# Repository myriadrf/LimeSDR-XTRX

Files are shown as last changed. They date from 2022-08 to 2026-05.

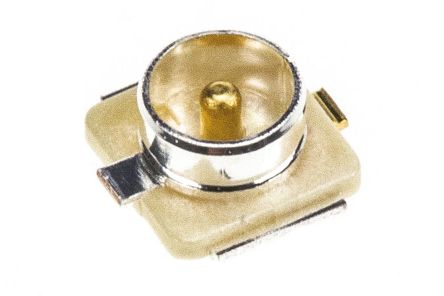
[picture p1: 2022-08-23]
hardware/rev5/Project Outputs/Pics/UFL connector.jpg

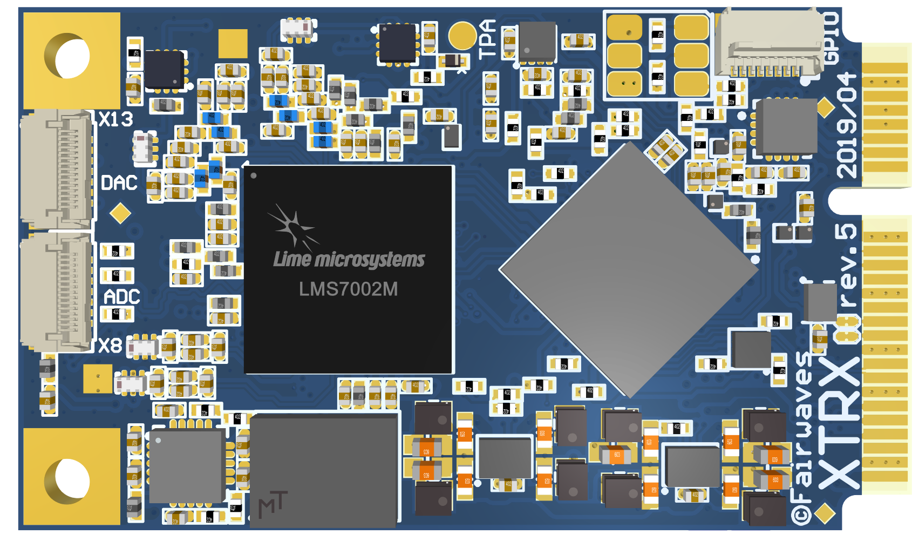
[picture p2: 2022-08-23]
hardware/rev5/Project Outputs/Pics/Bot.png

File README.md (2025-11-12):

# LimeSDR XTRX

LimeSDR XTRX is Small form factor mini PCIe expansion card Software Defined Radio (SDR) board. It provides a hardware platform for developing and prototyping high-performance and logic-intensive digital and RF designs based on Xilinx’s XC7A50T-2CPG236I FPGA and Lime Microsystems transceiver chipsets.

## Contents

The directory structure is as follows:

      hardware/<version>/
          OutputJobs/            - Output jobs
          PCB/                   - PCB design
          Project Outputs/       - BOM, rule check reports, Gerbers, pick & place files, PDFs
          Schematics/            - Schematic diagrams

The FPGA gateware is located in the [LimeSDR-XTRX_GW repo](https://github.com/myriadrf/LimeSDR-XTRX_GW).

## Documentation

The documentation sources for this project have been moved to the *docs* branch.

* [Hardware](https://limesdr-xtrx.myriadrf.org/)
* [Drivers](https://wiki.myriadrf.org/Lime_Suite) (Lime Suite)

## Licensing

The hardware designs are licensed under the Solderpad Hardware License v2.1.

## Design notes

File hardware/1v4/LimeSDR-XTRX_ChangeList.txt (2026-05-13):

Changes:
LimeSDR-XTRX_1v4(_DB)_DFMr0 created from LimeSDR-XTRX_1v3(_DB)_DFMr1:
 - Changed LMK buffer
 - Change USB FIFO chip because of EOL
 - Changed external CLK connectors from U.FL to MHF4
 - Added LMS TSTAO and TSTDO pin connections
 - Updated schematic template
 - All DFM files refreshed

LimeSDR-XTRX_1v3(_DB)_DFMr1:
 - BOM and schematic refreshed because of IC17 comment update
 - Other files (including DFM) left unchanged

LimeSDR-XTRX_1v3(_DB)_DFMr0:
 - Initial version

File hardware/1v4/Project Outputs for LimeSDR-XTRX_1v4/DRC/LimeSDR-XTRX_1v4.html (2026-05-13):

Altium

# Design Rule Verification Report

Date: | | 2026-05-13
Time: | | 12:01:15
Elapsed Time: | | 00:00:28
Filename: | | d:\LimePCBs\LimeSDR-XTRX\GIT\hardware\1v4\PCB\LimeSDR-XTRX_1v4.PcbDoc

Warnings: | | 0
Rule Violations: | | 0

## Summary

Warnings | Count
Total | 0

Rule Violations | Count
Clearance Constraint (Gap=0.1mm) (All),(All) | 0
Clearance Constraint (Gap=0.076mm) (WithinRoom('FPGA_fanout')),(All) | 0
Short-Circuit Constraint (Allowed=No) (All),(All) | 0
Un-Routed Net Constraint ( (All) ) | 0
Modified Polygon (Allow modified: No), (Allow shelved: No) | 0
Width Constraint (Min=0.1mm) (Max=7mm) (Preferred=0.2mm) (All) | 0
Width Constraint (Min=0.076mm) (Max=5mm) (Preferred=0.127mm) (WithinRoom('FPGA_fanout')) | 0
Width Constraint (Min=0.1mm) (Max=5mm) (Preferred=0.2mm) (All) | 0
Routing Layers(All) | 0
Routing Via (MinHoleWidth=0.15mm) (MaxHoleWidth=4.5mm) (PreferredHoleWidth=0.2mm) (MinWidth=0.3mm) (MaxWidth=5mm) (PreferedWidth=0.4mm) (All) | 0
Differential Pairs Uncoupled Length using the Gap Constraints (Min=0.1mm) (Max=0.3mm) (Prefered=0.1mm) and Width Constraints (Min=0.1mm) (Max=0.3mm) (Prefered=0.1mm) (InNetClass('RX_RF')) | 0
Differential Pairs Uncoupled Length using the Gap Constraints (Min=0.1mm) (Max=0.14mm) (Prefered=0.1mm) and Width Constraints (Min=0.1mm) (Max=0.2mm) (Prefered=0.1mm) (InNetClass('TX_RF')) | 0
Differential Pairs Uncoupled Length using the Gap Constraints (Min=0.1mm) (Max=0.3mm) (Prefered=0.14mm) and Width Constraints (Min=0.2mm) (Max=0.2mm) (Prefered=0.2mm) (InNetClass('FX3_DATA')) | 0
Differential Pairs Uncoupled Length using the Gap Constraints (Min=0.1mm) (Max=0.2mm) (Prefered=0.1mm) and Width Constraints (Min=0.1mm) (Max=0.4mm) (Prefered=0.1mm) (InNet('FX3_XTAL_N') or InNet('FX3_XTAL_P')) | 0
Differential Pairs Uncoupled Length using the Gap Constraints (Min=0.1mm) (Max=0.3mm) (Prefered=0.1mm) and Width Constraints (Min=0.1mm) (Max=0.5mm) (Prefered=0.2mm) (All) | 0
Power Plane Connect Rule(Relief Connect )(Expansion=0.508mm) (Conductor Width=0.254mm) (Air Gap=0.254mm) (Entries=4) (All) | 0
Hole Size Constraint (Min=0.15mm) (Max=10mm) (All) | 0
Pads and Vias to follow the Drill pairs settings | 0
Hole To Hole Clearance (Gap=0.15mm) (All),(All) | 0
Minimum Solder Mask Sliver (Gap=0.05mm) (All),(All) | 0
Net Antennae (Tolerance=0mm) (All) | 0
Matched Lengths(Tolerance=5mm) (InNetClass('FT_FIFO')) | 0
Matched Lengths(Tolerance=7.5mm) (InNetClass('LMS_PORT2')) | 0
Matched Lengths(Tolerance=7mm) (InNetClass('LMS_PORT1')) | 0
Component Clearance Constraint ( Horizontal Gap = -1mm, Vertical Gap = Infinite ) (HasFootprint('PCIe_MiniCard')),(All) | 0
Component Clearance Constraint ( Horizontal Gap = 0.01mm, Vertical Gap = 0.254mm ) (All),(All) | 0
Component Clearance Constraint ( Horizontal Gap = -1mm, Vertical Gap = Infinite ) (HasFootprint('MAX40200ANS+_IDEAL_DIODE_4WLP')),(HasFootprint('SOT23-5_v1')) | 0
Component Clearance Constraint ( Horizontal Gap = -10mm, Vertical Gap = Infinite ) (InComponent('MECH*') or InComponent('J3')),(All) | 0
Component Clearance Constraint ( Horizontal Gap = -1mm, Vertical Gap = Infinite ) (InComponent('R63') or InComponent('R66')),(InComponent('R63') or InComponent('R66')) | 0
Height Constraint (Min=0mm) (Max=25.4mm) (Prefered=12.7mm) (All) | 0
Total | 0

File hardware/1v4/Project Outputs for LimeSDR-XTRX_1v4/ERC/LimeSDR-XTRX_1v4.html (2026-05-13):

Altium

# Electrical Rule Check Report

Date: | | 2026-05-13
Time: | | 12:01:45
Filename: | | d:\LimePCBs\LimeSDR-XTRX\GIT\hardware\1v4\Project Outputs for LimeSDR-XTRX_1v4\ERC\LimeSDR-XTRX_1v4.html

Class | Document | Message
Warning | 10_Clock.SchDoc | FPGA_CLK contains IO Pin and Output Pin objects (Pin IC7-N17)

Warning

09_Misc.SchDoc

GND contains IO Pin and Power Pin objects (Pin IC30-2,Pin IC27-2,Pin IC25-2,Pin IC17-4,Pin IC13-4,Pin IC2-4,Pin IC4-7,Pin IC3-7,Pin IC7-A1,Pin IC7-A3,Pin IC7-A5,Pin IC7-A7,Pin IC7-A9,Pin IC7-A19,Pin IC7-B3,Pin IC7-B5,Pin IC7-B7,Pin IC7-B9,Pin IC7-B14,Pin IC7-C2,Pin IC19-C3,Pin IC7-C3,Pin IC7-C4,Pin IC7-C6,Pin IC7-C10,Pin IC7-C12,Pin IC7-C19,Pin IC7-D3,Pin IC7-E3,Pin IC7-E17,Pin IC7-E18,Pin IC4-EP,Pin IC3-EP,Pin IC7-F1,Pin IC7-F2,Pin IC7-F19,Pin IC7-G1,Pin IC7-G8,Pin IC7-G11,Pin IC7-H7,Pin IC7-H8,Pin IC7-H11,Pin IC7-H12,Pin IC7-H18,Pin IC7-J8,Pin IC7-J9,Pin IC7-J11,Pin IC7-J12,Pin IC7-K8,Pin IC7-L8,Pin IC7-L9,Pin IC7-L11,Pin IC7-L19,Pin IC7-M9,Pin IC7-M13,Pin IC7-N9,Pin IC7-N12,Pin IC7-N13,Pin IC7-P2,Pin IC7-P18,Pin IC13-PAD,Pin IC2-PAD,Pin IC7-T19,Pin IC7-U6,Pin IC7-U9,Pin IC7-V13,Pin IC7-V18,Pin IC7-W1,Pin IC7-W12)
Warning | 09_Misc.SchDoc | GNSS_1PPS contains IO Pin and Output Pin objects (Pin IC7-P3)
Warning | 09_Misc.SchDoc | GNSS_FIX contains IO Pin and Output Pin objects (Pin IC7-R18)
Warning | 08_FPGA.SchDoc | Net C0_N has no driving source (Pin C96-2,Pin IC7-A8)
Warning | 08_FPGA.SchDoc | Net C0_P has no driving source (Pin C95-2,Pin IC7-B8)
Warning | 09_Misc.SchDoc | Net FPGA_CFG_CCLK has no driving source (Pin IC7-C11,Pin IC18-6)
Warning | 08_FPGA.SchDoc | Net FPGA_PRG_B has no driving source (Pin C105-1,Pin IC7-V10,Pin R43-2,Pin TP3-1)
Warning | 09_Misc.SchDoc | Net GNSS_ANT has no driving source (Pin ESD5-1,Pin IC11-3,Pin L1-1,Pin X5-1)
Warning | 05_LMS7002M_Misc.SchDoc | Net LMS_I2C_SCL has no driving source (Pin IC1-C27,Pin IC2-6,Pin R4-1)
Warning | 08_FPGA.SchDoc | Net M0 has no driving source (Pin IC7-V12,Pin R42-2)
Warning | 08_FPGA.SchDoc | Net MGTRREF_216 has no driving source (Pin IC7-C7,Pin R40-2)
Warning | 08_FPGA.SchDoc | Net NetC106_1 has no driving source (Pin C106-1,Pin IC7-A12,Pin R46-1,Pin R47-1,Pin R48-1)
Warning | 10_Clock.SchDoc | Net NetC156_2 has no driving source (Pin C156-2,Pin IC8-13)
Warning | 10_Clock.SchDoc | Net NetC165_2 has no driving source (Pin C165-2,Pin IC8-28)
Warning | 10_Clock.SchDoc | Net NetC172_2 has no driving source (Pin C172-2,Pin IC8-14)
Warning | 11_Power.SchDoc | Net NetC175_2 has no driving source (Pin C175-2,Pin FR54-2,Pin IC21-1,Pin IC21-6,Pin R105-1)
Warning | 10_Clock.SchDoc | Net NetC192_2 has no driving source (Pin C192-2,Pin IC8-27)
Warning | 11_Power.SchDoc | Net NetC203_2 has no driving source (Pin C203-2,Pin FR45-2,Pin IC26-1,Pin IC26-6,Pin R108-1)
Warning | 11_Power.SchDoc | Net NetC209_2 has no driving source (Pin C209-2,Pin FR49-2,Pin IC29-1,Pin IC29-6,Pin R115-1)
Warning | 11_Power.SchDoc | Net NetC220_2 has no driving source (Pin C220-2,Pin FR50-2,Pin IC32-1,Pin IC32-6,Pin R118-1)
Warning | 09_Misc.SchDoc | Net NetFR36_2 has no driving source (Pin FR36-2,Pin IC11-9)
Warning | 10_Clock.SchDoc | Net NetIC8_31 has no driving source (Pin IC8-31,Pin R149-2)
Warning | 10_Clock.SchDoc | Net NetIC17_2 has no driving source (Pin IC17-2,Pin R68-2,Pin R69-2)
Warning | 09_Misc.SchDoc | Net NetIC19_B1 has no driving source (Pin IC19-B1,Pin R81-2)
Warning | 11_Power.SchDoc | Net NetIC21_5 has no driving source (Pin IC21-5,Pin R106-2,Pin R107-1)
Warning | 11_Power.SchDoc | Net NetIC26_5 has no driving source (Pin IC26-5,Pin R112-2,Pin R113-1)
Warning | 11_Power.SchDoc | Net NetIC29_5 has no driving source (Pin IC29-5,Pin R116-2,Pin R117-1)
Warning | 11_Power.SchDoc | Net NetIC32_5 has no driving source (Pin IC32-5,Pin R122-2,Pin R123-1)
Warning | 08_FPGA.SchDoc | Net PCI_REF_CLK1_N has no driving source (Pin IC7-A10,Pin TP2-1)
Warning | 08_FPGA.SchDoc | Net PCI_REF_CLK1_P has no driving source (Pin IC7-B10,Pin TP1-1)
Warning | 08_FPGA.SchDoc | Net R0_N has no driving source (Pin C103-2,Pin IC7-A6)
Warning | 08_FPGA.SchDoc | Net R0_P has no driving source (Pin C101-2,Pin IC7-B6)
Warning | 08_FPGA.SchDoc | Net R1_N has no driving source (Pin C99-2,Pin IC7-A4)
Warning | 08_FPGA.SchDoc | Net R1_P has no driving source (Pin C97-2,Pin IC7-B4)
Warning | 08_FPGA.SchDoc | Net TCK_0 has no driving source (Pin IC7-C8,Pin R34-2,Pin R39-2)
Warning | 08_FPGA.SchDoc | Net TDI_0 has no driving source (Pin IC7-W10,Pin R35-2,Pin R37-2)
Warning | 08_FPGA.SchDoc | Net TMS_0 has no driving source (Pin IC7-W9,Pin R36-2,Pin R41-2)
Warning | 10_Clock.SchDoc | Net XO_VC has no driving source (Pin C184-1,Pin R66-2,Pin R67-2,Pin R70-1,Pin XO1-1)
Warning | 09_Misc.SchDoc | USB_DIR contains IO Pin and Output Pin objects (Pin IC7-B18)
Warning | 09_Misc.SchDoc | USB_NXT contains IO Pin and Output Pin objects (Pin IC7-A18)

Back to top

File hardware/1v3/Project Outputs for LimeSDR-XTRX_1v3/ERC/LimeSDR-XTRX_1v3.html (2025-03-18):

Altium

# Electrical Rule Check Report

Date: | | 2024-12-06
Time: | | 14:26:39
Filename: | | d:\LimePCBs\LimeSDR-XTRX\GIT\hardware\1v3\Project Outputs for LimeSDR-XTRX_1v3\ERC\LimeSDR-XTRX_1v3.html

Class | Document | Message

Warning

09_Misc.SchDoc

GND contains IO Pin and Power Pin objects (Pin IC30-2,Pin IC27-2,Pin IC25-2,Pin IC17-4,Pin IC13-4,Pin IC2-4,Pin IC4-7,Pin IC3-7,Pin IC7-A1,Pin IC7-A3,Pin IC7-A5,Pin IC7-A7,Pin IC7-A9,Pin IC7-A19,Pin IC7-B3,Pin IC7-B5,Pin IC7-B7,Pin IC7-B9,Pin IC7-B14,Pin IC7-C2,Pin IC7-C3,Pin IC7-C4,Pin IC7-C6,Pin IC7-C10,Pin IC7-C12,Pin IC7-C19,Pin IC7-D3,Pin IC7-E3,Pin IC7-E17,Pin IC7-E18,Pin IC4-EP,Pin IC3-EP,Pin IC7-F1,Pin IC7-F2,Pin IC7-F19,Pin IC7-G1,Pin IC7-G8,Pin IC7-G11,Pin IC7-H7,Pin IC7-H8,Pin IC7-H11,Pin IC7-H12,Pin IC7-H18,Pin IC7-J8,Pin IC7-J9,Pin IC7-J11,Pin IC7-J12,Pin IC7-K8,Pin IC7-K18,Pin IC7-L8,Pin IC7-L9,Pin IC7-L11,Pin IC7-L19,Pin IC7-M9,Pin IC7-M13,Pin IC7-N9,Pin IC7-N12,Pin IC7-N13,Pin IC7-P2,Pin IC13-PAD,Pin IC2-PAD,Pin IC7-T19,Pin IC7-U6,Pin IC7-U9,Pin IC7-V18,Pin IC7-W1,Pin IC7-W12)
Warning | 09_Misc.SchDoc | GNSS_1PPS contains IO Pin and Output Pin objects (Pin IC7-P3)
Warning | 09_Misc.SchDoc | GNSS_FIX contains IO Pin and Output Pin objects (Pin IC7-R18)
Warning | 01_Block_Diagram.SchDoc | Incorrect link between project variant "Default" and schematic component Component C185 100nF, 6.3V
Warning | 08_FPGA.SchDoc | Net C0_N has no driving source (Pin C96-2,Pin IC7-A8)
Warning | 08_FPGA.SchDoc | Net C0_P has no driving source (Pin C95-2,Pin IC7-B8)
Warning | 09_Misc.SchDoc | Net FPGA_CFG_CCLK has no driving source (Pin IC7-C11,Pin IC18-6)
Warning | 08_FPGA.SchDoc | Net FPGA_PRG_B has no driving source (Pin C105-1,Pin IC7-V10,Pin R43-2,Pin TP3-1)
Warning | 09_Misc.SchDoc | Net GNSS_ANT has no driving source (Pin ESD5-1,Pin IC11-3,Pin L1-1,Pin X5-1)
Warning | 05_LMS7002M_Misc.SchDoc | Net LMS_I2C_SCL has no driving source (Pin IC1-C27,Pin IC2-6,Pin R4-1)
Warning | 08_FPGA.SchDoc | Net M0 has no driving source (Pin IC7-V12,Pin R42-2)
Warning | 08_FPGA.SchDoc | Net MGTRREF_216 has no driving source (Pin IC7-C7,Pin R40-2)
Warning | 08_FPGA.SchDoc | Net NetC106_1 has no driving source (Pin C106-1,Pin IC7-A12,Pin R46-1,Pin R47-1,Pin R48-1)
Warning | 11_Power.SchDoc | Net NetC175_2 has no driving source (Pin C175-2,Pin FR54-2,Pin IC21-1,Pin IC21-6,Pin R105-1)
Warning | 11_Power.SchDoc | Net NetC203_2 has no driving source (Pin C203-2,Pin FR45-2,Pin IC26-1,Pin IC26-6,Pin R108-1)
Warning | 11_Power.SchDoc | Net NetC209_2 has no driving source (Pin C209-2,Pin FR49-2,Pin IC29-1,Pin IC29-6,Pin R115-1)
Warning | 11_Power.SchDoc | Net NetC220_2 has no driving source (Pin C220-2,Pin FR50-2,Pin IC32-1,Pin IC32-6,Pin R118-1)
Warning | 09_Misc.SchDoc | Net NetFR36_2 has no driving source (Pin FR36-2,Pin IC11-9)
Warning | 10_Clock.SchDoc | Net NetIC17_2 has no driving source (Pin IC17-2,Pin R68-2,Pin R69-2)
Warning | 11_Power.SchDoc | Net NetIC21_5 has no driving source (Pin IC21-5,Pin R106-2,Pin R107-1)
Warning | 11_Power.SchDoc | Net NetIC26_5 has no driving source (Pin IC26-5,Pin R112-2,Pin R113-1)
Warning | 11_Power.SchDoc | Net NetIC29_5 has no driving source (Pin IC29-5,Pin R116-2,Pin R117-1)
Warning | 11_Power.SchDoc | Net NetIC32_5 has no driving source (Pin IC32-5,Pin R122-2,Pin R123-1)
Warning | 08_FPGA.SchDoc | Net PCI_REF_CLK1_N has no driving source (Pin IC7-A10,Pin TP2-1)
Warning | 08_FPGA.SchDoc | Net PCI_REF_CLK1_P has no driving source (Pin IC7-B10,Pin TP1-1)
Warning | 08_FPGA.SchDoc | Net R0_N has no driving source (Pin C103-2,Pin IC7-A6)
Warning | 08_FPGA.SchDoc | Net R0_P has no driving source (Pin C101-2,Pin IC7-B6)
Warning | 08_FPGA.SchDoc | Net R1_N has no driving source (Pin C99-2,Pin IC7-A4)
Warning | 08_FPGA.SchDoc | Net R1_P has no driving source (Pin C97-2,Pin IC7-B4)
Warning | 08_FPGA.SchDoc | Net TCK_0 has no driving source (Pin IC7-C8,Pin R34-2,Pin R39-2)
Warning | 08_FPGA.SchDoc | Net TDI_0 has no driving source (Pin IC7-W10,Pin R35-2,Pin R37-2)
Warning | 08_FPGA.SchDoc | Net TMS_0 has no driving source (Pin IC7-W9,Pin R36-2,Pin R41-2)
Warning | 10_Clock.SchDoc | Net XO_VC has no driving source (Pin C184-1,Pin R66-2,Pin R67-2,Pin R70-1,Pin XO1-1)

Back to top

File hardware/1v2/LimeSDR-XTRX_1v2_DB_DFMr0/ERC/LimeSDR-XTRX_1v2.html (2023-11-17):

Altium

# Electrical Rule Check Report

Date: | | 2023-11-17
Time: | | 17:05:38
Filename: | | d:\LimePCBs\LimeSDR-XTRX\GIT\hardware\1v2\Project Outputs for LimeSDR-XTRX_1v2\ERC\LimeSDR-XTRX_1v2.html

Class | Document | Message

Warning

09_Misc.SchDoc

GND contains IO Pin and Power Pin objects (Pin IC30-2,Pin IC27-2,Pin IC25-2,Pin IC17-4,Pin IC13-4,Pin IC2-4,Pin IC4-7,Pin IC3-7,Pin IC7-A1,Pin IC7-A3,Pin IC7-A5,Pin IC7-A7,Pin IC7-A9,Pin IC7-A19,Pin IC7-B3,Pin IC7-B5,Pin IC7-B7,Pin IC7-B9,Pin IC7-B14,Pin IC7-C2,Pin IC7-C3,Pin IC7-C4,Pin IC7-C6,Pin IC7-C10,Pin IC7-C12,Pin IC7-C19,Pin IC7-D3,Pin IC7-E3,Pin IC7-E17,Pin IC7-E18,Pin IC4-EP,Pin IC3-EP,Pin IC7-F1,Pin IC7-F2,Pin IC7-F19,Pin IC7-G1,Pin IC7-G8,Pin IC7-G11,Pin IC7-H7,Pin IC7-H8,Pin IC7-H11,Pin IC7-H12,Pin IC7-H18,Pin IC7-J8,Pin IC7-J9,Pin IC7-J11,Pin IC7-J12,Pin IC7-K8,Pin IC7-K18,Pin IC7-L8,Pin IC7-L9,Pin IC7-L11,Pin IC7-L19,Pin IC7-M9,Pin IC7-M13,Pin IC7-N9,Pin IC7-N12,Pin IC7-N13,Pin IC7-P2,Pin IC13-PAD,Pin IC2-PAD,Pin IC7-T19,Pin IC7-U6,Pin IC7-U9,Pin IC7-V13,Pin IC7-V18,Pin IC7-W1,Pin IC7-W12)
Warning | 09_Misc.SchDoc | GNSS_1PPS contains IO Pin and Output Pin objects (Pin IC7-P3)
Warning | 09_Misc.SchDoc | GNSS_FIX contains IO Pin and Output Pin objects (Pin IC7-R18)
Warning | 08_FPGA.SchDoc | Net C0_N has no driving source (Pin C96-2,Pin IC7-A8)
Warning | 08_FPGA.SchDoc | Net C0_P has no driving source (Pin C95-2,Pin IC7-B8)
Warning | 09_Misc.SchDoc | Net FPGA_CFG_CCLK has no driving source (Pin IC7-C11,Pin IC18-6)
Warning | 08_FPGA.SchDoc | Net FPGA_PRG_B has no driving source (Pin C105-1,Pin IC7-V10,Pin R43-2,Pin TP3-1)
Warning | 09_Misc.SchDoc | Net GNSS_ANT has no driving source (Pin ESD5-1,Pin IC11-3,Pin L1-1,Pin X5-1)
Warning | 05_LMS7002M_Misc.SchDoc | Net LMS_I2C_SCL has no driving source (Pin IC1-C27,Pin IC2-6,Pin R4-1)
Warning | 08_FPGA.SchDoc | Net M0 has no driving source (Pin IC7-V12,Pin R42-2)
Warning | 08_FPGA.SchDoc | Net MGTRREF_216 has no driving source (Pin IC7-C7,Pin R40-2)
Warning | 08_FPGA.SchDoc | Net NetC106_1 has no driving source (Pin C106-1,Pin IC7-A12,Pin R46-1,Pin R47-1,Pin R48-1)
Warning | 10_Power.SchDoc | Net NetC192_2 has no driving source (Pin C192-2,Pin FR42-2,Pin IC21-1,Pin IC21-6,Pin R105-1)
Warning | 10_Power.SchDoc | Net NetC203_2 has no driving source (Pin C203-2,Pin FR45-2,Pin IC26-1,Pin IC26-6,Pin R108-1)
Warning | 10_Power.SchDoc | Net NetC209_2 has no driving source (Pin C209-2,Pin FR49-2,Pin IC29-1,Pin IC29-6,Pin R115-1)
Warning | 10_Power.SchDoc | Net NetC220_2 has no driving source (Pin C220-2,Pin FR50-2,Pin IC32-1,Pin IC32-6,Pin R118-1)
Warning | 09_Misc.SchDoc | Net NetFR36_2 has no driving source (Pin FR36-2,Pin IC11-9)
Warning | 09_Misc.SchDoc | Net NetIC17_2 has no driving source (Pin IC17-2,Pin R68-2,Pin R69-2)
Warning | 10_Power.SchDoc | Net NetIC21_5 has no driving source (Pin IC21-5,Pin R106-2,Pin R107-1)
Warning | 10_Power.SchDoc | Net NetIC26_5 has no driving source (Pin IC26-5,Pin R112-2,Pin R113-1)
Warning | 10_Power.SchDoc | Net NetIC29_5 has no driving source (Pin IC29-5,Pin R116-2,Pin R117-1)
Warning | 10_Power.SchDoc | Net NetIC32_5 has no driving source (Pin IC32-5,Pin R122-2,Pin R123-1)
Warning | 08_FPGA.SchDoc | Net PCI_REF_CLK1_N has no driving source (Pin IC7-A10,Pin TP2-1)
Warning | 08_FPGA.SchDoc | Net PCI_REF_CLK1_P has no driving source (Pin IC7-B10,Pin TP1-1)
Warning | 08_FPGA.SchDoc | Net R0_N has no driving source (Pin C103-2,Pin IC7-A6)
Warning | 08_FPGA.SchDoc | Net R0_P has no driving source (Pin C101-2,Pin IC7-B6)
Warning | 08_FPGA.SchDoc | Net R1_N has no driving source (Pin C99-2,Pin IC7-A4)
Warning | 08_FPGA.SchDoc | Net R1_P has no driving source (Pin C97-2,Pin IC7-B4)
Warning | 08_FPGA.SchDoc | Net TCK_0 has no driving source (Pin IC7-C8,Pin R34-2,Pin R39-2)
Warning | 08_FPGA.SchDoc | Net TDI_0 has no driving source (Pin IC7-W10,Pin R35-2,Pin R37-2)
Warning | 08_FPGA.SchDoc | Net TMS_0 has no driving source (Pin IC7-W9,Pin R36-2,Pin R41-2)
Warning | 09_Misc.SchDoc | Net XO_VC has no driving source (Pin C184-1,Pin R66-2,Pin R67-2,Pin R70-1,Pin XO1-1)

Back to top

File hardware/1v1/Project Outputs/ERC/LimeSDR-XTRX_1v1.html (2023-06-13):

Altium

# Electrical Rule Check Report

Date: | | 2023-04-14
Time: | | 16:12:55
Filename: | | E:\Saniok\Lime Micro\Lime PCBs\LimeSDR-XTRX\LimeSDR-XTRX_1v1\Altium Designer design files\Project Outputs for LimeSDR-XTRX_1v1\ERC\LimeSDR-XTRX_1v1.html

Class | Document | Message
Warning | 09_Misc.SchDoc | FPGA_CLK contains IO Pin and Output Pin objects (Pin IC7-N17)

Warning

09_Misc.SchDoc

GND contains IO Pin and Power Pin objects (Pin IC29-2,Pin IC26-2,Pin IC24-2,Pin IC16-4,Pin IC13-4,Pin IC2-4,Pin IC4-7,Pin IC3-7,Pin IC7-A1,Pin IC7-A3,Pin IC7-A5,Pin IC7-A7,Pin IC7-A9,Pin IC7-A19,Pin IC7-B3,Pin IC7-B5,Pin IC7-B7,Pin IC7-B9,Pin IC7-B14,Pin IC7-C2,Pin IC7-C3,Pin IC7-C4,Pin IC7-C6,Pin IC7-C10,Pin IC7-C12,Pin IC7-C19,Pin IC7-D3,Pin IC7-E3,Pin IC7-E17,Pin IC7-E18,Pin IC4-EP,Pin IC3-EP,Pin IC7-F1,Pin IC7-F2,Pin IC7-F19,Pin IC7-G1,Pin IC7-G8,Pin IC7-G11,Pin IC7-H7,Pin IC7-H8,Pin IC7-H11,Pin IC7-H12,Pin IC7-H18,Pin IC7-J8,Pin IC7-J9,Pin IC7-J11,Pin IC7-J12,Pin IC7-K8,Pin IC7-K18,Pin IC7-L8,Pin IC7-L9,Pin IC7-L11,Pin IC7-L19,Pin IC7-M9,Pin IC7-M13,Pin IC7-N9,Pin IC7-N12,Pin IC7-N13,Pin IC7-P2,Pin IC7-P18,Pin IC13-PAD,Pin IC2-PAD,Pin IC7-T19,Pin IC7-U6,Pin IC7-U9,Pin IC7-V18,Pin IC7-W1,Pin IC7-W12)
Warning | 09_Misc.SchDoc | GNSS_1PPS contains IO Pin and Output Pin objects (Pin IC7-P3)
Warning | 09_Misc.SchDoc | GNSS_FIX contains IO Pin and Output Pin objects (Pin IC7-R18)
Warning | 08_FPGA.SchDoc | Net C0_N has no driving source (Pin C96-2,Pin IC7-A8)
Warning | 08_FPGA.SchDoc | Net C0_P has no driving source (Pin C95-2,Pin IC7-B8)
Warning | 09_Misc.SchDoc | Net FPGA_CFG_CCLK has no driving source (Pin IC7-C11,Pin IC17-6)
Warning | 08_FPGA.SchDoc | Net FPGA_PRG_B has no driving source (Pin C105-1,Pin IC7-V10,Pin R43-2,Pin TP3-1)
Warning | 09_Misc.SchDoc | Net GNSS_ANT has no driving source (Pin ESD5-1,Pin IC10-3,Pin L1-1,Pin X5-1)
Warning | 05_LMS7002M_Misc.SchDoc | Net LMS_I2C_SCL has no driving source (Pin IC1-C27,Pin IC2-6,Pin R4-1)
Warning | 08_FPGA.SchDoc | Net M0 has no driving source (Pin IC7-V12,Pin R42-2)
Warning | 08_FPGA.SchDoc | Net MGTRREF_216 has no driving source (Pin IC7-C7,Pin R40-2)
Warning | 08_FPGA.SchDoc | Net NetC106_1 has no driving source (Pin C106-1,Pin IC7-A12,Pin R47-1,Pin R49-1,Pin R50-1)
Warning | 09_Misc.SchDoc | Net NetC157_2 has no driving source (Pin C157-2,Pin IC9-2,Pin R56-1)
Warning | 10_Power.SchDoc | Net NetC188_2 has no driving source (Pin C188-2,Pin FR43-2,Pin IC20-1,Pin IC20-6,Pin R103-1)
Warning | 10_Power.SchDoc | Net NetC199_2 has no driving source (Pin C199-2,Pin FR46-2,Pin IC25-1,Pin IC25-6,Pin R106-1)
Warning | 10_Power.SchDoc | Net NetC205_2 has no driving source (Pin C205-2,Pin FR49-2,Pin IC28-1,Pin IC28-6,Pin R113-1)
Warning | 10_Power.SchDoc | Net NetC216_2 has no driving source (Pin C216-2,Pin FR50-2,Pin IC31-1,Pin IC31-6,Pin R116-1)
Warning | 09_Misc.SchDoc | Net NetFR36_2 has no driving source (Pin FR36-2,Pin IC10-9)
Warning | 09_Misc.SchDoc | Net NetIC11_2 has no driving source (Pin IC11-2,Pin IC12-4,Pin IC14-2,Pin R58-1)
Warning | 09_Misc.SchDoc | Net NetIC16_2 has no driving source (Pin IC16-2,Pin R66-2,Pin R67-2)
Warning | 10_Power.SchDoc | Net NetIC20_5 has no driving source (Pin IC20-5,Pin R104-2,Pin R105-1)
Warning | 10_Power.SchDoc | Net NetIC25_5 has no driving source (Pin IC25-5,Pin R110-2,Pin R111-1)
Warning | 10_Power.SchDoc | Net NetIC28_5 has no driving source (Pin IC28-5,Pin R114-2,Pin R115-1)
Warning | 10_Power.SchDoc | Net NetIC31_5 has no driving source (Pin IC31-5,Pin R120-2,Pin R121-1)
Warning | 08_FPGA.SchDoc | Net PCI_REF_CLK1_N has no driving source (Pin IC7-A10,Pin TP2-1)
Warning | 08_FPGA.SchDoc | Net PCI_REF_CLK1_P has no driving source (Pin IC7-B10,Pin TP1-1)
Warning | 08_FPGA.SchDoc | Net R0_N has no driving source (Pin C103-2,Pin IC7-A6)
Warning | 08_FPGA.SchDoc | Net R0_P has no driving source (Pin C101-2,Pin IC7-B6)
Warning | 08_FPGA.SchDoc | Net R1_N has no driving source (Pin C99-2,Pin IC7-A4)
Warning | 08_FPGA.SchDoc | Net R1_P has no driving source (Pin C97-2,Pin IC7-B4)
Warning | 08_FPGA.SchDoc | Net TCK_0 has no driving source (Pin IC7-C8,Pin R34-2,Pin R39-2)
Warning | 08_FPGA.SchDoc | Net TDI_0 has no driving source (Pin IC7-W10,Pin R35-2,Pin R37-2)
Warning | 08_FPGA.SchDoc | Net TMS_0 has no driving source (Pin IC7-W9,Pin R36-2,Pin R41-2)
Warning | 09_Misc.SchDoc | Net XO_VC has no driving source (Pin C178-1,Pin R64-2,Pin R65-2,Pin R68-1,Pin XO1-1)

Back to top

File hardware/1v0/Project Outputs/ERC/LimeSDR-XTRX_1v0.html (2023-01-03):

Altium

# Electrical Rule Check Report

Date: | | 2022-12-29
Time: | | 14:01:02
Filename: | | E:\Saniok\Lime Micro\Lime PCBs\LimeSDR-XTRX_1v0\Altium Designer design files1\Project Outputs for LimeSDR-XTRX_1v0\ERC\LimeSDR-XTRX_1v0.html

Class | Document | Message
Warning | 09_Misc.SchDoc | FPGA_CLK contains IO Pin and Output Pin objects (Pin IC7-N17)

Warning

09_Misc.SchDoc

GND contains IO Pin and Power Pin objects (Pin IC29-2,Pin IC26-2,Pin IC24-2,Pin IC16-4,Pin IC13-4,Pin IC2-4,Pin IC4-7,Pin IC3-7,Pin IC7-A1,Pin IC7-A3,Pin IC7-A5,Pin IC7-A7,Pin IC7-A9,Pin IC7-A19,Pin IC7-B3,Pin IC7-B5,Pin IC7-B7,Pin IC7-B9,Pin IC7-B14,Pin IC7-C2,Pin IC7-C3,Pin IC7-C4,Pin IC7-C6,Pin IC7-C10,Pin IC7-C12,Pin IC7-C19,Pin IC7-D3,Pin IC7-E3,Pin IC7-E17,Pin IC7-E18,Pin IC4-EP,Pin IC3-EP,Pin IC7-F1,Pin IC7-F2,Pin IC7-F19,Pin IC7-G1,Pin IC7-G8,Pin IC7-G11,Pin IC7-H7,Pin IC7-H8,Pin IC7-H11,Pin IC7-H12,Pin IC7-H18,Pin IC7-J8,Pin IC7-J9,Pin IC7-J11,Pin IC7-J12,Pin IC7-K8,Pin IC7-K18,Pin IC7-L8,Pin IC7-L9,Pin IC7-L11,Pin IC7-L19,Pin IC7-M9,Pin IC7-M13,Pin IC7-N9,Pin IC7-N12,Pin IC7-N13,Pin IC7-P2,Pin IC7-P18,Pin IC13-PAD,Pin IC2-PAD,Pin IC7-T19,Pin IC7-U6,Pin IC7-U9,Pin IC7-V13,Pin IC7-V18,Pin IC7-W1,Pin IC7-W12)
Warning | 09_Misc.SchDoc | GNSS_1PPS contains IO Pin and Output Pin objects (Pin IC7-P3)
Warning | 09_Misc.SchDoc | GNSS_FIX contains IO Pin and Output Pin objects (Pin IC7-R18)
Warning | 08_FPGA.SchDoc | Net C0_N has no driving source (Pin C96-2,Pin IC7-A8)
Warning | 08_FPGA.SchDoc | Net C0_P has no driving source (Pin C95-2,Pin IC7-B8)
Warning | 09_Misc.SchDoc | Net FPGA_CFG_CCLK has no driving source (Pin IC7-C11,Pin IC17-6)
Warning | 08_FPGA.SchDoc | Net FPGA_PRG_B has no driving source (Pin C105-1,Pin IC7-V10,Pin R43-2,Pin TP3-1)
Warning | 09_Misc.SchDoc | Net GNSS_ANT has no driving source (Pin ESD5-1,Pin IC10-3,Pin L1-1,Pin X5-1)
Warning | 05_LMS7002M_Misc.SchDoc | Net LMS_I2C_SCL has no driving source (Pin IC1-C27,Pin IC2-6,Pin R4-1)
Warning | 08_FPGA.SchDoc | Net M0 has no driving source (Pin IC7-V12,Pin R42-2)
Warning | 08_FPGA.SchDoc | Net MGTRREF_216 has no driving source (Pin IC7-C7,Pin R40-2)
Warning | 08_FPGA.SchDoc | Net NetC106_1 has no driving source (Pin C106-1,Pin IC7-A12,Pin R47-1,Pin R49-1,Pin R50-1)
Warning | 09_Misc.SchDoc | Net NetC157_2 has no driving source (Pin C157-2,Pin IC9-2,Pin R56-1)
Warning | 10_Power.SchDoc | Net NetC188_2 has no driving source (Pin C188-2,Pin FR43-2,Pin IC20-1,Pin IC20-6,Pin R103-1)
Warning | 10_Power.SchDoc | Net NetC199_2 has no driving source (Pin C199-2,Pin FR46-2,Pin IC25-1,Pin IC25-6,Pin R106-1)
Warning | 10_Power.SchDoc | Net NetC205_2 has no driving source (Pin C205-2,Pin FR49-2,Pin IC28-1,Pin IC28-6,Pin R112-1)
Warning | 10_Power.SchDoc | Net NetC216_2 has no driving source (Pin C216-2,Pin FR50-2,Pin IC31-1,Pin IC31-6,Pin R115-1)
Warning | 09_Misc.SchDoc | Net NetFR36_2 has no driving source (Pin FR36-2,Pin IC10-9)
Warning | 09_Misc.SchDoc | Net NetIC11_2 has no driving source (Pin IC11-2,Pin IC12-4,Pin IC14-2,Pin R58-1)
Warning | 09_Misc.SchDoc | Net NetIC16_2 has no driving source (Pin IC16-2,Pin R66-2,Pin R67-2)
Warning | 10_Power.SchDoc | Net NetIC20_5 has no driving source (Pin IC20-5,Pin R104-2,Pin R105-1)
Warning | 10_Power.SchDoc | Net NetIC25_5 has no driving source (Pin IC25-5,Pin R110-2,Pin R111-1)
Warning | 10_Power.SchDoc | Net NetIC28_5 has no driving source (Pin IC28-5,Pin R113-2,Pin R114-1)
Warning | 10_Power.SchDoc | Net NetIC31_5 has no driving source (Pin IC31-5,Pin R119-2,Pin R120-1)
Warning | 08_FPGA.SchDoc | Net PCI_REF_CLK1_N has no driving source (Pin IC7-A10,Pin TP2-1)
Warning | 08_FPGA.SchDoc | Net PCI_REF_CLK1_P has no driving source (Pin IC7-B10,Pin TP1-1)
Warning | 08_FPGA.SchDoc | Net R0_N has no driving source (Pin C103-2,Pin IC7-A6)
Warning | 08_FPGA.SchDoc | Net R0_P has no driving source (Pin C101-2,Pin IC7-B6)
Warning | 08_FPGA.SchDoc | Net R1_N has no driving source (Pin C99-2,Pin IC7-A4)
Warning | 08_FPGA.SchDoc | Net R1_P has no driving source (Pin C97-2,Pin IC7-B4)
Warning | 08_FPGA.SchDoc | Net SEL_VFLSH has no driving source (Pin IC7-V11,Pin R46-1,Pin R48-1)
Warning | 08_FPGA.SchDoc | Net TCK_0 has no driving source (Pin IC7-C8,Pin R34-2,Pin R39-2)
Warning | 08_FPGA.SchDoc | Net TDI_0 has no driving source (Pin IC7-W10,Pin R35-2,Pin R37-2)
Warning | 08_FPGA.SchDoc | Net TMS_0 has no driving source (Pin IC7-W9,Pin R36-2,Pin R41-2)
Warning | 09_Misc.SchDoc | Net XO_VC has no driving source (Pin C178-1,Pin R64-2,Pin R65-2,Pin R68-1,Pin XO1-1)

Back to top

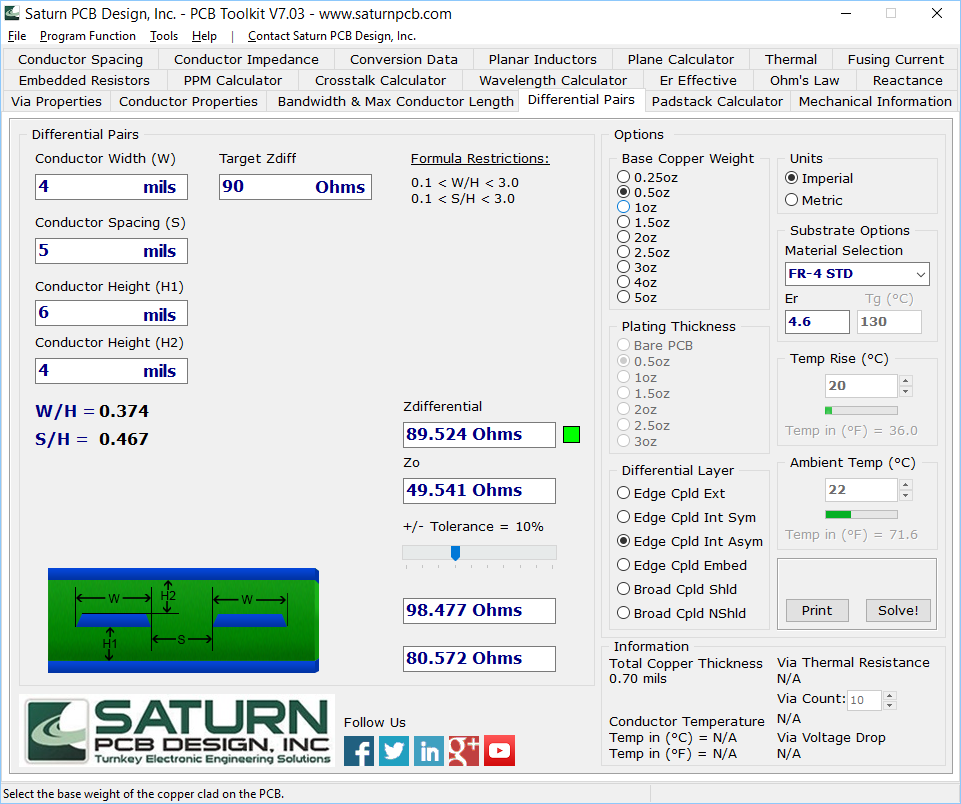
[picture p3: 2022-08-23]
hardware/rev5/Project Outputs/Pics/8L diff inner 3 90.png

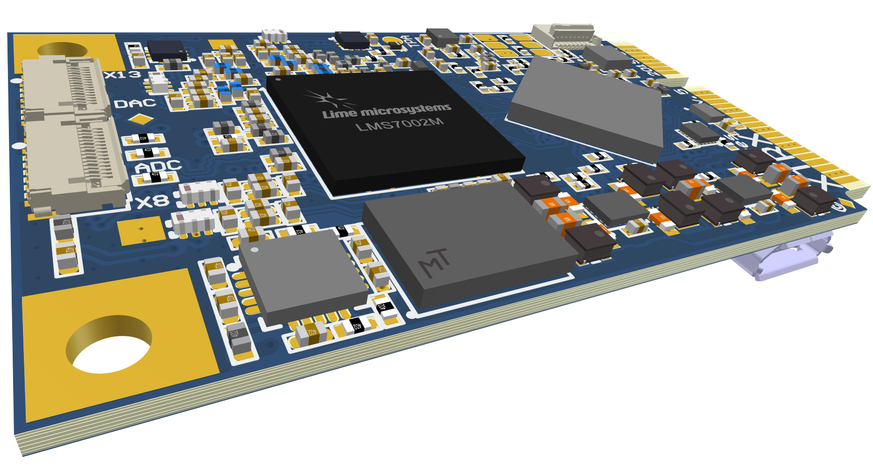
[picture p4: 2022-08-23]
hardware/rev5/Project Outputs/Pics/Iso Bot.png

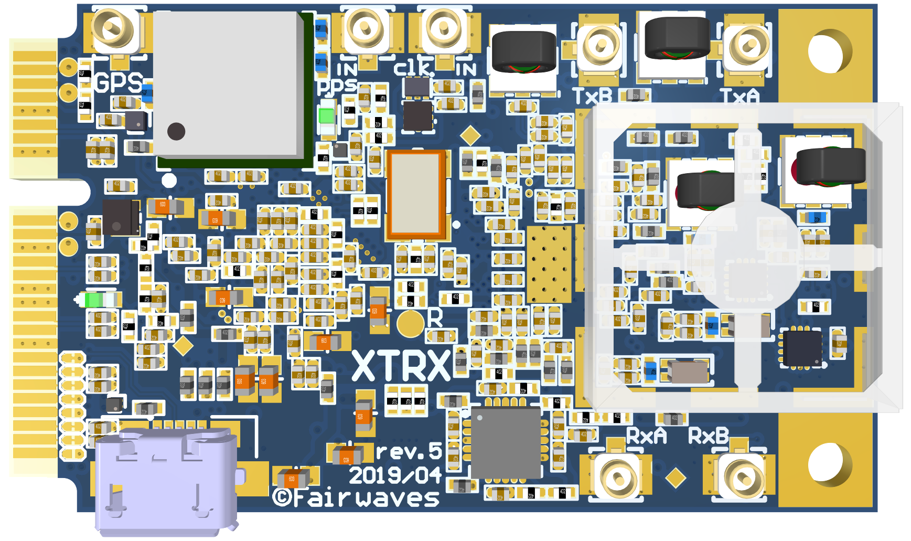
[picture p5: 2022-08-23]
hardware/rev5/Project Outputs/Pics/Top.png

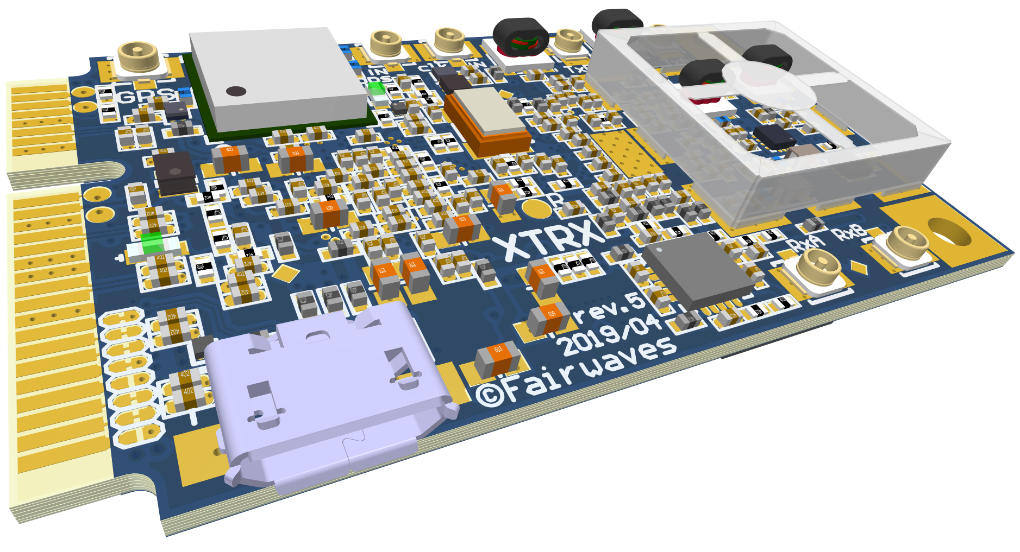
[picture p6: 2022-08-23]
hardware/rev5/Project Outputs/Pics/Iso Top.png

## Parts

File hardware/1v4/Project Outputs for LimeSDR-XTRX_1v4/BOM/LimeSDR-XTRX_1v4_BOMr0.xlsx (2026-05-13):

Item # | Comment | Quantity | Designator | Footprint | Manufacturer | Manufacturer Part Number 1 | Supplier 1 | Supplier Part Number 1 | Part Description | Additional Info
1 | 1uF, 6.3V | 59 | C1, C35, C37, C38, C39, C40, C41, C42, C44, C46, C48, C49, C50, C51, C53, C54, C55, C56, C57, C58, C59, C60, C61, C62, C63, C64, C65, C67, C68, C69, C70, C71, C72, C74, C76, C78, C80, C82, C83, C84, C85, C86, C87, C88, C89, C90, C91, C92, C93, C94, C166, C180, C187, C188, C189, C190, C193, C198, C227 | CAP0201 | TDK Corporation | JMK063ABJ105MP-F | Digi-Key | 587-5864-2-ND | 1µF ±20% 6.3V X5R Ceramic Capacitor -55°C ~ 85°C Surface Mount, MLCC 0201 (0603 Metric) 0.024" L x 0.012" W (0.60mm x 0.30mm)
2 | 22pF, 50V | 5 | C2, C163, C164, C167, C169 | CAP0201 | Murata | GRM0335C1H220JA01D | Digi-Key | 490-6123-1-ND | 22 pF ±5% 50V Ceramic Capacitor C0G, NP0 0201 (0603 Metric)
3 | 100pF, 50V | 16 | C3, C4, C5, C7, C11, C12, C13, C14, C157, C168, C170, C173, C194, C195, C199, C200 | CAP0201 | TDK | C0603C0G1H101J030BA | Digi-Key | 445-1786-1-ND | 100 pF ±5% 50V Ceramic Capacitor C0G, NP0 0201 (0603 Metric)
4 | 100nF, 10V | 46 | C6, C8, C9, C10, C15, C16, C17, C18, C27, C28, C33, C34, C95, C96, C97, C98, C99, C100, C101, C102, C103, C104, C105, C108, C109, C111, C112, C155, C156, C159, C161, C162, C165, C172, C181, C182, C183, C184, C185, C191, C192, C196, C197, C201, C218, C233 | CAP0201 | Samsung | CL03A104MP3NNNC | Digi-Key | 1276-1321-1-ND | 0.1 µF ±20% 10V Ceramic Capacitor X5R 0201 (0603 Metric)
5 | 1nF, 25V | 21 | C19, C20, C25, C26, C29, C30, C31, C32, C36, C43, C45, C47, C52, C66, C73, C75, C77, C79, C81, C106, C158 | CAP0201 | TDK Corporation | C0603X7R1E102K030BA | Digi-Key | 445-7275-1-ND | 1000pF ±10% 25V X7R Ceramic Capacitor -55°C ~ 125°C Surface Mount, MLCC 0201 (0603 Metric) 0.024" L x 0.012" W (0.60mm x 0.30mm)
6 | 510pF, 50V | 4 | C21, C22, C23, C24 | CAP0402 | Murata Electronics North America | GRM1555C1H511JA01D | Digi-Key | 490-3237-1-ND | 510pF ±5% 50V C0G, NP0 Ceramic Capacitor -55°C ~ 125°C Surface Mount, MLCC 0402 (1005 Metric) 0.039" L x 0.020" W (1.00mm x 0.50mm)
7 | 4.7uF, 6.3V | 24 | C107, C110, C113, C117, C118, C126, C127, C132, C133, C141, C142, C147, C148, C171, C175, C176, C179, C203, C204, C209, C210, C220, C221, C224 | CAP0402 | Murata Electronics North America | GRM155R60J475ME87D | Digi-Key | 490-5408-1-ND | 4.7µF ±20% 6.3V X5R Ceramic Capacitor -55°C ~ 85°C Surface Mount, MLCC 0402 (1005 Metric) 0.039" L x 0.020" W (1.00mm x 0.50mm)
8 | 470nF, 6.3V | 22 | C114, C115, C119, C120, C121, C122, C128, C129, C130, C131, C134, C135, C136, C137, C143, C144, C145, C146, C149, C150, C151, C152 | CAP0201 | Murata | GRM033R60J474KE90D | Digi-Key | 490-10409-1-ND | 0.47 µF ±10% 6.3V Ceramic Capacitor X5R 0201 (0603 Metric)
9 | 47uF, 6.3V | 17 | C116, C123, C124, C125, C138, C139, C140, C153, C154, C178, C202, C205, C212, C216, C219, C222, C231 | CAP0603 | Murata | GRM188R60J476ME15D | Digi-Key | 490-13247-1-ND | 47 µF ±20% 6.3V Ceramic Capacitor X5R 0603 (1608 Metric)
10 | 10uF, 10V | 10 | C177, C207, C211, C213, C215, C217, C225, C226, C229, C232 | CAP0603 | Murata | GRM188R61A106ME69D | Digi-Key | 490-10475-1-ND | 10 µF ±20% 10V Ceramic Capacitor X5R 0603 (1608 Metric)
11 | 1uF, 10V | 2 | C186, C206 | CAP0402 | TDK | C1005X5R1E105K050BC | Digi-Key | 445-9066-1-ND | 1µF ±10% 10V X5R Ceramic Capacitor -55°C ~ 85°C Surface Mount, MLCC 0402 (1005 Metric) 0.039" L x 0.020" W (1.00mm x 0.50mm)
12 | ESD8472 | 3 | ESD6, ESD7, ESD8 | ESD8472_X3DFN2 | ON Semiconductor | ESD8472MUT5G | Digi-Key | ESD8472MUT5GOSCT-ND | TVS DIODE 5.3VWM 14VC X3DFN2
13 | Fiducial | 8 | F1, F2, F3, F4, F5, F6, F7, F8 | Fiducial
14 | Fiducial | 2 | FL1, FL2 | Fiducial_local
15 | 600R, 0.27A | 42 | FR1, FR2, FR3, FR4, FR5, FR6, FR7, FR8, FR9, FR10, FR11, FR12, FR13, FR14, FR15, FR16, FR17, FR18, FR19, FR20, FR21, FR22, FR23, FR24, FR25, FR26, FR27, FR28, FR29, FR30, FR31, FR32, FR33, FR34, FR35, FR36, FR37, FR39, FR41, FR42, FR48, FR53 | RES0201 | Taiyo Yuden | BK0603TS601-T | Digi-Key | 587-3277-1-ND | FERRITE BEAD 600 OHM 0201 1LN
16 | 220R, 0.9A | 11 | FR38, FR40, FR43, FR44, FR45, FR46, FR49, FR50, FR51, FR52, FR54 | RES0402 | TDK Corporation | MPZ1005S221ET000 | Digi-Key | 445-9329-2-ND | FERRITE BEAD 220 OHM 0402 1LN
17 | 600R, 2A | 1 | FR47 | RES0805 | TDK Corporation | MPZ2012S601AT000 | Digi-Key | 445-2206-2-ND | FERRITE BEAD 600 OHM 0805 1LN
18 | LMS7002M | 1 | IC1 | LMS7002M_v5_LESS_SILK | Lime Microsystems | LMS7002M | Lime Microsystems | LMS7002M | IC FPRF Transceiver LMS7002M; 261 pin aQFN
19 | SKY13414-485LF | 2 | IC3, IC4 | SKY13414-485LF_RF_SW_QFN14 | Skyworks Solutions | SKY13414-485LF | Digi-Key | 863-1582-1-ND | RF Switch IC General Purpose SP4T 3 GHz 50Ohm 14-QFN (2x2)
20 | SKY13330-397LF | 2 | IC5, IC6 | SKY13330-397LF_RF_SW_QFN12 | Skyworks Solutions | SKY13330-397LF | Digi-Key | 863-1643-1-ND | RF Switch IC W-CDMA SPDT 6 GHz 50Ohm 12-QFN (2x2)
21 | XC7A50T-2CPG236I | 1 | IC7 | XC7A35T-2CPG236 | Xilinx | XC7A50T-2CPG236I | Digi-Key | 122-2181-ND | Artix-7 Field Programmable Gate Array (FPGA) IC 106 2764800 52160 238-LFBGA, CSPBGA
22 | LMK00101 | 1 | IC8 | LMK00101_WQFN32_r1 | Texas Instruments | LMK00101SQE/NOPB | Digi-Key | 296-39036-1-ND | Clock Fanout Buffer (Distribution), Multiplexer, Translator IC 200MHz 32-WFQFN Exposed Pad
23 | TMP1075NDRLR | 1 | IC9 | TMP1075NDRLR_temperature_sensor_SOT563 | Texas Instruments | TMP1075NDRLR | Digi-Key | 296-TMP1075NDRLRCT-ND | Temperature Sensor Digital, Local -40°C ~ 125°C 12 b SOT-563
24 | GNSS M10578-A3 | 1 | IC11 | M10578-A3_v2 | Antenova | M10578-A3 | Digi-Key | 627-1074-1-ND | RADIONOVA RF Receiver GPS 1.575GHz -165dBm Module
25 | NVT4555UKZ | 1 | IC16 | NVT4555UKZ_SIM_INTERFACE_WLCSP12 | NXP Semiconductors | NVT4555UKZ | Digi-Key | 568-11436-1-ND | SIM Card Interface 12-WLCSP (1.20x1.60)
26 | AD5693BCPZ-RL7 | 1 | IC17 | AD5693RACPZ-1RL7_DAC_8LFCSP | Analog Devices | AD5693BCPZ-RL7 | Digikey | 505-AD5693BCPZ-RL7CT-ND | 16 Bit Digital to Analog Converter 1 8-LFCSP-UD (2x2)
27 | MX25L25645GZ2I-08G | 1 | IC18 | S25FL164K_WSON8_DFN6 | Macronix | MX25L25645GZ2I-08G | Digi-Key | 1092-1237-ND | FLASH - NOR Memory IC 256Mbit SPI 120 MHz 8-WSON (8x6)
28 | USB3317C-GJ-TR | 1 | IC19 | USB3317C-GJ-TR_USB2_transceiver | Microchip | USB3317C-GJ-TR | DigiKey | 150-USB3317C-GJ-TRCT-ND | IC TXRX USB 2.0 FLEXPWR 25BGA
29 | PI5A23157ZUAEX | 1 | IC20 | PI5A23157ZUAEX_SPDT_SW_10UQFN | Diodes | PI5A23157ZUAEX | Digi-Key | 31-PI5A23157ZUAEXCT-ND | 2 Circuit IC Switch 2:1 15Ohm 10-UQFN (1.5x2)
30 | LD39100PUR | 3 | IC21, IC26, IC29 | LD39100PUR | STMicroelectronics | LD39100PUR | Digi-Key | 497-11013-1-ND | Linear Voltage Regulator IC Positive Adjustable Output 0.8 V ~ 4.5 V 1A 6-DFN (3x3)
31 | LP8758A1E0YFFR | 2 | IC22, IC31 | LP8758A1E0YFFR_QUAD_DC-DC_35DSBGA | Texas Instruments | LP8758A1E0YFFR | Digi-Key | 296-47808-1-ND | Buck Switching Regulator IC Positive Programmable 0.5V 4 Output 4A 35-UFBGA, DSBGA
32 | MAX40200ANS+ | 3 | IC23, IC24, IC28 | MAX40200ANS+_IDEAL_DIODE_4WLP | Maxim | MAX40200ANS+ | Digi-Key | MAX40200ANS+-ND | OR Controller Source Selector Switch P-Channel 1:1 4-WLP (0.73x0.73)
33 | LM4040 | 1 | IC33 | SOT23-3_v3 | Diodes | LM4040C30FTA | Digi-Key | LM4040C30FTADICT-ND | Shunt Voltage Reference IC Fixed 3V V ±0.5% 15 mA SOT-23-3
34 | 47nH | 1 | L1 | RES0402 | COILCRAFT | 0402HP-47NXJLU | Farnell | 2285856 | INDUCTOR, RF, 47NH, 5%, 2.4GHZ, SMD; Product Range:0402HP Series; Inductance:47nH; Inductance Tolerance:± 5%; High Frequency Inductor Case:0402 [1005 Metric]; Self Resonant Frequency Min:2.4GHz; DC Resistance Max:0.58ohm; DC Current Rating:420mA
35 | 0.47uH, 4A | 8 | L2, L3, L4, L5, L6, L7, L8, L9 | IND0806 | TDK | VLS201610HBX-R47M-1 | Digi-Key | 445-172395-1-ND | 470 nH Shielded Drum Core, Wirewound Inductor 2.81 A 41mOhm Max 0806 (2016 Metric)
36 | LED_green | 2 | LED1, LED2 | LED0201 | Kingbright | APG0603CGC-TT | Digi-Key | 754-2021-1-ND | Green 571nm LED Indication - Discrete 1.97V 2-SMD, 0201
37 | BMI-S-202-C | 1 | MECH1 | BMI-S-202-C_RF_SHIELD_COVER | Laird | BMI-S-202-C | Digi-Key | 903-1014-ND | RF Shield Cover 0.668" (16.96mm) X 0.668" (16.96mm) Vent Holes in Pattern Snap Fit
38 | BMI-S-202-F | 1 | MECH2 | BMI-S-202-F_RF_SHIELD_FRAME_v3 | Laird | BMI-S-202-F | Digi-Key | 903-1051-1-ND | RF Shield Frame 0.650" (16.50mm) X 0.650" (16.50mm) Surface Mount
39 | 10 nH, 5% | 6 | MN1, MN2, MN3, MN4, MN47, MN48 | RES0402 | Murata | LQW15AN10NJ00D | Digi-Key | 490-1146-6-ND | RF Inductors - SMD 10 NH 5%
40 | 10 pF, 50V | 8 | MN5, MN6, MN11, MN12, MN37, MN38, MN43, MN44 | CAP0402 | Walsin Technologies | 0402N100D500CT | Digi-Key | 1292-0402N100D500CT-ND | 10 pF ±0.5pF 50V Ceramic Capacitor C0G, NP0 0402 (1005 Metric)
41 | 100uH | 4 | MN13, MN14, MN15, MN16 | RES0805 | TDK Corporation | MLF2012C101KT000 | Digi-Key | 445-1071-1-ND | FIXED IND 100UH 2MA 3.1 OHM SMD
42 | 0R | 8 | MN17, MN18, MN19, MN20, R27, R31, R201, R202 | RES0402 | Yageo | RC0402JR-070RL | Digi-Key | 311-0.0JRTR-ND | RES SMD 0.0OHM JUMPER 1/16W 0402
43 | 100nF, 16V | 4 | MN21, MN22, MN27, MN28 | CAP0402 | Murata Electronics | GRM155R71C104KA88D | Mouser | 81-GRM155R71C104KA88 | 0.10µF ±10% 16V X7R Ceramic Capacitor -55°C ~ 125°C Surface Mount, MLCC 0402 (1005 Metric) 0.039" L x 0.020" W (1.00mm x 0.50mm)
44 | 2pF, 50V | 2 | MN24, MN26 | CAP0402 | AVX | 04025U2R0BAT2A | Farnell | 2332536 | SMD Multilayer Ceramic Capacitor, U Series, 2 pF, ± 0.1pF, C0G / NP0, 50 V, 0402 [1005 Metric]
45 | 470pF, 50V | 4 | MN29, MN30, MN35, MN36 | CAP0402 | TDK Corporation | C1005C0G1H471J050BA | Digi-Key | 445-2656-6-ND | 470pF ±5% 50V Ceramic Capacitor C0G, NP0 0402 (1005 Metric)
46 | 100pF, 50V | 4 | MN45, MN46, MN51, MN52 | CAP0402 | Yageo | CC0402JRNPO9BN101 | Digi-Key | 311-1024-1-ND | 100pF ±5% 50V C0G, NP0 Ceramic Capacitor -55°C ~ 125°C Surface Mount, MLCC 0402 (1005 Metric) 0.039" L x 0.020" W (1.00mm x 0.50mm)
47 | 0.8pF | 2 | MN49, MN50 | CAP0402 | Murata Electronics North America | GRM1555C1HR80BA01D | Digi-Key | 490-6269-1-ND | 0.80pF ±0.1pF 50V C0G, NP0 Ceramic Capacitor -55°C ~ 125°C Surface Mount, MLCC 0402 (1005 Metric) 0.039" L x 0.020" W (1.00mm x 0.50mm)
48 | 47R, 1% | 6 | R1, R10, R11, R12, R13, R72 | RES0201 | Yageo | RC0201FR-0747RL | Digi-Key | YAG2694CT-ND | 47 Ohms ±1% 0.05W, 1/20W Chip Resistor 0201 (0603 Metric) Moisture Resistant Thick Film
49 | 15R, 1% | 12 | R2, R14, R37, R38, R39, R41, R53, R75, R77, R82, R85, R94 | RES0201 | Yageo | RC0201FR-0715RL | Digi-Key | 311-15.0MCT-ND | 15 Ohms ±1% 0.05W, 1/20W Chip Resistor 0201 (0603 Metric) Moisture Resistant Thick Film
50 | 3k, 1% | 4 | R3, R4, R46, R47 | RES0201 | Yageo | RC0201FR-073KL | Digi-Key | YAG2656CT-ND | 3 kOhms ±1% 0.05W, 1/20W Chip Resistor 0201 (0603 Metric) Moisture Resistant Thick Film
51 | 10k, 1% | 14 | R5, R6, R7, R8, R9, R15, R16, R34, R35, R36, R84, R107, R113, R117 | RES0201 | Yageo | RC0201FR-0710KL | Digi-Key | 311-10.0KMCT-ND | 10 kOhms ±1% 0.05W, 1/20W Chip Resistor 0201 (0603 Metric) Moisture Resistant Thick Film
52 | 100R, 1% | 7 | R17, R18, R19, R20, R40, R66, R124 | RES0201 | Yageo | RC0201FR-07100RL | Digi-Key | 311-100MCT-ND | 100 Ohms ±1% 0.05W, 1/20W Chip Resistor 0201 (0603 Metric) Moisture Resistant Thick Film
53 | 1k, 1% | 5 | R21, R22, R23, R48, R71 | RES0201 | Yageo | RC0201FR-071KL | Digi-Key | 311-1KMDKR-ND | 1 kOhms ±1% 0.05W, 1/20W Chip Resistor 0201 (0603 Metric) Moisture Resistant Thick Film
54 | 4.7k, 1% | 8 | R24, R25, R26, R43, R45, R83, R86, R87 | RES0201 | Yageo | RC0201FR-074K7L | Digi-Key | 311-4.70KMCT-ND | 4.7 kOhms ±1% 0.05W, 1/20W Chip Resistor 0201 (0603 Metric) Moisture Resistant Thick Film
55 | 10R | 4 | R28, R29, R32, R33 | RES0201 | Panasonic Electronic Components | ERJ-1GEF10R0C | Digi-Key | P10.0ABCT-ND | RES SMD 10 OHM 1% 1/20W 0201
56 | 0R | 25 | R30, R49, R50, R51, R68, R76, R78, R89, R92, R93, R95, R96, R97, R98, R100, R101, R102, R103, R118, R126, R149, R151, R153, R154, R155 | RES0201 | Yageo | RC0201JR-070RL | Digi-Key | 311-0.0NCT-ND | 0 Ohms Jumper Chip Resistor 0201 (0603 Metric) Moisture Resistant Thick Film
57 | 330R, 1% | 5 | R42, R44, R80, R99, R104 | RES0201 | Vishay Dale | CRCW0201330RFKED | Digi-Key | 541-330AABCT-ND | 330 Ohms ±1% 0.05W, 1/20W Chip Resistor 0201 (0603 Metric) Thick Film
58 | 12.7k, 1% | 2 | R74, R116 | RES0201 | Yageo | RC0201FR-0712K7L | Digi-Key | 311-12.7KMCT-ND | 12.7 kOhms ±1% 0.05W, 1/20W Chip Resistor 0201 (0603 Metric) Moisture Resistant Thick Film
59 | 8.06k, 1% | 1 | R91 | RES0201 | Yageo | RC0201FR-078K06L | Digi-Key | YAG2831CT-ND | 8.06 kOhms ±1% 0.05W, 1/20W Chip Resistor 0201 (0603 Metric) Moisture Resistant Thick Film
60 | 5.6k, 1% | 1 | R106 | RES0201 | Yageo | RC0201FR-075K6L | Digi-Key | YAG2346CT-ND | 5.6 kOhms ±1% 0.05W, 1/20W Chip Resistor 0201 (0603 Metric) Moisture Resistant Thick Film
61 | 3k3, 1% | 5 | R109, R111, R119, R120, R121 | RES0201 | Yageo | RC0201FR-073K3L | Digi-Key | YAG2285CT-ND | 3.3 kOhms ±1% 0.05W, 1/20W Chip Resistor 0201 (0603 Metric) Moisture Resistant Thick Film
62 | 47k, 1% | 1 | R110 | RES0201 | Yageo | RC0201FR-0747KL | Digi-Key | 311-47KMCT-ND | 47 kOhms ±1% 0.05W, 1/20W Chip Resistor 0201 (0603 Metric) Moisture Resistant Thick Film
63 | 7.5k, 1% | 1 | R112 | RES0201 | Stackpole Electronics | RMCF0201FT7K50 | Digi-Key | RMCF0201FT7K50CT-ND | 7.5 kOhms ±1% 0.05W, 1/20W Chip Resistor 0201 (0603 Metric) Thick Film
64 | 3600BL14M050 | 4 | T1, T2, T7, T8 | 3600BL14M050_balun_0603 | Johanson | 3600BL14M050T | Digi-Key | 712-1048-1-ND | Signal Conditioning 3.6GHz 1:1 BALUN
65 | TC1-1-13M-45+ | 4 | T3, T4, T9, T10 | TC1-1-13MA+_JA4220-AL_ | Minicircuits | TC1-1-13M-45+ | Minicircuits | TC1-1-13M-45+ | RF balun; 1:1 ratio; 3 dB bandwidth: 0.3 MHz to 3.5 GHz; 3.8mm x 3.8mm
66 | B0322J5050AHF | 2 | T5, T6 | Anaren_0805_balun_B0322J5050AHF | Anaren | B0322J5050AHF | Mouser | 620-B0322J5050AHF | Signal Conditioning 300-2200MHz 50 Ohm IL=1.6dB
67 | U.FL/MMCX | 5 | X1, X2, X3, X4, X5 | MMCX_UFL_conn_u_v2 | Molex, LLC | 0734120110 | Digi-Key | WM5587CT-ND | Ultra Miniature Coaxial Connector Receptacle, Male Pin 50 Ohm Surface Mount Solder
68 | MHF4 | 3 | X6, X7, X14 | IPEX_MHF4_conn | TE Connectivity / Linx Technologies | CONMHF4-SMD-G-T | Digikey | 343-CONMHF4-SMD-G-TCT-ND | IPEX MHF4 Connector Jack, Male Pin 50 Ohms Surface Mount Solder
69 | 5025981593 | 2 | X8, X13 | 5025981593_FPC_connector | Molex | 5025981593 | Digi-Key | 900-5025981593CT-ND | 15 Position FPC Connector Contacts, Top and Bottom 0.012" (0.30mm) Surface Mount, Right Angle
70 | USB Micro Type B | 1 | X11 | USB_Micro_TypeB_47346-0001 | Molex | 47346-0001 | Digi-Key | WM17141CT-ND | USB - micro B USB 2.0 Receptacle Connector 5 Position Surface Mount, Right Angle
71 | 8-pin FPC connector | 1 | X12 | 503480-0800_8PIN_FPC_CONN | Molex | 503480-0800 | Digi-Key | WM1388CT-ND | 8 Position FFC, FPC Connector Contacts, Top and Bottom 0.020" (0.50mm) Surface Mount, Right Angle
72 | E6982LF | 1 | XO1 | RAKON_E8231LF_E6982LF | Rakon | E6982LF | Rakon | E6982LF | 26MHz E6982LF Small Cell TCVCXO, w EN and VC, L x W: 5.0 x 3.2 mm nom., H: 2.1 mm max. (6 pad)

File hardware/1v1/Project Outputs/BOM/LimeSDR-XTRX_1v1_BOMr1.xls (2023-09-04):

Item # | Comment | Quantity | Designator | Footprint | Manufacturer | Manufacturer Part Number 1 | Supplier 1 | Supplier Part Number 1 | Part Description | Assembly Info | Number of NF parts in row | Number of fitted parts in row
1 | 1uF, 6.3V | 57 | C1, C35, C37, C38, C39, C40, C41, C42, C44, C46, C48, C49, C50, C51, C53, C54, C55, C56, C57, C58, C59, C60, C61, C62, C63, C64, C65, C67, C68, C69, C70, C71, C72, C74, C76, C78, C80, C82, C83, C84, C85, C86, C87, C88, C89, C90, C91, C92, C93, C94, C174, C176, C183, C184, C185, C186, C222 | CAP0201 | TDK Corporation | JMK063ABJ105MP-F | Digi-Key | 587-5864-2-ND | 1µF ±20% 6.3V X5R Ceramic Capacitor -55°C ~ 85°C Surface Mount, MLCC 0201 (0603 Metric) 0.024" L x 0.012" W (0.60mm x 0.30mm) |  |  | 57
2 | 22pF, 50V | 5 | C2, C161, C162, C163, C165 | CAP0201 | Murata | GRM0335C1H220JA01D | Digi-Key | 490-6123-1-ND | 22 pF ±5% 50V Ceramic Capacitor C0G, NP0 0201 (0603 Metric) |  |  | 5
3 | 100pF, 50V | 13 | C3, C4, C5, C7, C11, C12, C13, C14, C166, C194, C204, C210, C219 | CAP0201 | TDK | C0603C0G1H101J030BA | Digi-Key | 445-1786-1-ND | 100 pF ±5% 50V Ceramic Capacitor C0G, NP0 0201 (0603 Metric) | NF(C194 C204 C210 C219) | 4 | 9
4 | 100nF, 6.3V | 43 | C6, C8, C9, C10, C15, C16, C17, C18, C27, C28, C33, C34, C95, C96, C97, C98, C99, C100, C101, C102, C103, C104, C105, C108, C109, C111, C112, C158, C159, C160, C168, C170, C172, C173, C177, C178, C179, C180, C181, C187, C197, C214, C223 | CAP0201 | Samsung | CL03A104MP3NNNC | Digi-Key | 1276-1321-1-ND | 100 pF ±5% 50V Ceramic Capacitor C0G, NP0 0201 (0603 Metric) | NF(C170 C223) | 2 | 41
5 | 1nF, 25V | 25 | C19, C20, C25, C26, C29, C30, C31, C32, C36, C43, C45, C47, C52, C66, C73, C75, C77, C79, C81, C106, C156, C157, C164, C169, C171 | CAP0201 | TDK Corporation | C0603X7R1E102K030BA | Digi-Key | 445-7275-1-ND | 1000pF ±10% 25V X7R Ceramic Capacitor -55°C ~ 125°C Surface Mount, MLCC 0201 (0603 Metric) 0.024" L x 0.012" W (0.60mm x 0.30mm) |  |  | 25
6 | 510pF, 50V | 4 | C21, C22, C23, C24 | CAP0402 | Murata Electronics North America | GRM1555C1H511JA01D | Digi-Key | 490-3237-1-ND | 510pF ±5% 50V C0G, NP0 Ceramic Capacitor -55°C ~ 125°C Surface Mount, MLCC 0402 (1005 Metric) 0.039" L x 0.020" W (1.00mm x 0.50mm) |  |  | 4
7 | 4.7uF, 6.3V | 24 | C107, C110, C113, C117, C118, C127, C128, C133, C134, C142, C143, C148, C149, C167, C175, C188, C189, C199, C200, C205, C206, C216, C217, C220 | CAP0402 | Murata Electronics North America | GRM155R60J475ME87D | Digi-Key | 490-5408-1-ND | 4.7µF ±20% 6.3V X5R Ceramic Capacitor -55°C ~ 85°C Surface Mount, MLCC 0402 (1005 Metric) 0.039" L x 0.020" W (1.00mm x 0.50mm) |  |  | 24
8 | 470nF, 6.3V | 22 | C114, C115, C119, C120, C121, C122, C129, C130, C131, C132, C135, C136, C137, C138, C144, C145, C146, C147, C150, C151, C152, C153 | CAP0201 | Murata | GRM033R60J474KE90D | Digi-Key | 490-10409-1-ND | 0.47 µF ±10% 6.3V Ceramic Capacitor X5R 0201 (0603 Metric) |  |  | 22
9 | 47uF, 6.3V | 17 | C116, C123, C124, C125, C139, C140, C141, C154, C155, C191, C195, C198, C201, C208, C212, C215, C218 | CAP0603 | Murata | GRM188R60J476ME15D | Digi-Key | 490-13247-1-ND | 47 µF ±20% 6.3V Ceramic Capacitor X5R 0603 (1608 Metric) |  |  | 17
10 | 1uF, 10V | 2 | C182, C202 | CAP0402 | TDK | C1005X5R1E105K050BC | Digi-Key | 445-9066-1-ND | 1µF ±10% 10V X5R Ceramic Capacitor -55°C ~ 85°C Surface Mount, MLCC 0402 (1005 Metric) 0.039" L x 0.020" W (1.00mm x 0.50mm) |  |  | 2
11 | 10uF, 10V | 10 | C190, C192, C193, C196, C203, C207, C209, C211, C213, C221 | CAP0603 | Murata | GRM188R61A106ME69D | Digi-Key | 490-10475-1-ND | 10 µF ±20% 10V Ceramic Capacitor X5R 0603 (1608 Metric) |  |  | 10
12 | ESD8472 | 6 | ESD1, ESD2, ESD3, ESD4, ESD5, ESD6 | ESD8472_X3DFN2 | ON Semiconductor | ESD8472MUT5G | Digi-Key | ESD8472MUT5GOSCT-ND | TVS DIODE 5.3VWM 14VC X3DFN2 | NF(ESD1 ESD2 ESD3 ESD4 ESD5) | 5 | 1
13 | Fiducial | 8 | F1, F2, F3, F4, F5, F6, F7, F8 | Fiducial |  |  |  |  |  |  |  | 8
14 | Fiducial | 2 | FL1, FL2 | Fiducial_local |  |  |  |  |  |  |  | 2
15 | 600R, 0.27A | 40 | FR1, FR2, FR3, FR4, FR5, FR6, FR7, FR8, FR9, FR10, FR11, FR12, FR13, FR14, FR15, FR16, FR17, FR18, FR19, FR20, FR21, FR22, FR23, FR24, FR25, FR26, FR27, FR28, FR29, FR30, FR31, FR32, FR33, FR34, FR35, FR36, FR37, FR39, FR40, FR42 | RES0201 | Taiyo Yuden | BK0603TS601-T | Digi-Key | 587-3277-1-ND | FERRITE BEAD 600 OHM 0201 1LN |  |  | 40
16 | 220R, 0.9A | 11 | FR38, FR41, FR43, FR44, FR45, FR46, FR47, FR49, FR50, FR51, FR52 | RES0402 | TDK Corporation | MPZ1005S221ET000 | Digi-Key | 445-9329-2-ND | FERRITE BEAD 220 OHM 0402 1LN |  |  | 11
17 | 600R, 2A | 1 | FR48 | RES0805 | TDK Corporation | MPZ2012S601AT000 | Digi-Key | 445-2206-2-ND | FERRITE BEAD 600 OHM 0805 1LN |  |  | 1
18 | LMS7002M | 1 | IC1 | LMS7002M_v5_LESS_SILK | Lime Microsystems | LMS7002M | Lime Microsystems | LMS7002M | IC FPRF Transceiver LMS7002M; 261 pin aQFN |  |  | 1
19 | M24128 | 2 | IC2, IC13 | M24128-DFMC6TG | STMicroelectronics | M24128-DFMC6TG | Digi-Key | 497-15739-1-ND | EEPROM Memory IC 128Kb (16K x 8) I²C 1MHz 450ns 8-UFDFPN (2x3) | NF(IC2 IC13) | 2 | 0
20 | SKY13414-485LF | 2 | IC3, IC4 | SKY13414-485LF_RF_SW_QFN14 | Skyworks Solutions | SKY13414-485LF | Digi-Key | 863-1582-1-ND | RF Switch IC General Purpose SP4T 3 GHz 50Ohm 14-QFN (2x2) |  |  | 2
21 | SKY13330-397LF | 2 | IC5, IC6 | SKY13330-397LF_RF_SW_QFN12 | Skyworks Solutions | SKY13330-397LF | Digi-Key | 863-1643-1-ND | RF Switch IC W-CDMA SPDT 6 GHz 50Ohm 12-QFN (2x2) |  |  | 2
22 | XC7A50T-2CPG236I | 1 | IC7 | XC7A35T-2CPG236 | Xilinx | XC7A50T-2CPG236I | Digi-Key | 122-2181-ND | Artix-7 Field Programmable Gate Array (FPGA) IC 106 2764800 52160 238-LFBGA, CSPBGA |  |  | 1
23 | TMP1075NDRLR | 1 | IC8 | TMP1075NDRLR_temperature_sensor_SOT563 | Texas Instruments | TMP1075NDRLR | Digi-Key | 296-TMP1075NDRLRCT-ND | Temperature Sensor Digital, Local -40°C ~ 125°C 12 b SOT-563 |  |  | 1
24 | 74LVC1G34QSE-7 | 3 | IC9, IC11, IC14 | 74AHCT1G126SE-7_BUFFER_SOT353 | Diodes | 74LVC1G34QSE-7 | Mouser | 621-74LVC1G34QSE-7 | Buffers & Line Drivers Logic LVC 1 Gate SOT353 T&R 3K |  |  | 3
25 | GNSS M10578-A3 | 1 | IC10 | M10578-A3_v2 | Antenova | M10578-A3 | Digi-Key | 627-1074-1-ND | RADIONOVA RF Receiver GPS 1.575GHz -165dBm Module |  |  | 1
26 | 74LVC1G3157FZ4 | 1 | IC12 | 74LVC1G3157FZ4_SPDT_SW_DFN1410-6 | Diodes | 74LVC1G3157FZ4-7 | Digi-Key | 74LVC1G3157FZ4-7DICT-ND | 1 Circuit IC Switch 2:1 10Ohm X2-DFN1410-6 |  |  | 1
27 | NVT4555UKZ | 1 | IC15 | NVT4555UKZ_SIM_INTERFACE_WLCSP12 | NXP Semiconductors | NVT4555UKZ | Digi-Key | 568-11436-1-ND | SIM Card Interface 12-WLCSP (1.20x1.60) |  |  | 1
28 | AD5693RACPZ | 1 | IC16 | AD5693RACPZ-1RL7_DAC_8LFCSP | Analog Devices | AD5693RACPZ-1RL7 | Mouser | 584-AD5693RACPZ-1RL7 | Digital to Analog Converters - DAC 16-BIT 12C nanoDAC+ with on-chip ref |  |  | 1
29 | MX25L25645GZ2I-08G | 1 | IC17 | S25FL164K_WSON8_DFN6 | Macronix | MX25L25645GZ2I-08G | Digi-Key | 1092-1237-ND | FLASH - NOR Memory IC 256Mbit SPI 120 MHz 8-WSON (8x6) |  |  | 1
30 | USB3333E-GL | 1 | IC18 | USB3333E-GL_USB_PHY_25WLCSP | Microchip | USB3333E-GL-TR | Digi-Key | USB3333E-GL-TR-ND | Transceiver Half USB 2.0 25-WLCSP (1.97x1.97) |  |  | 1
31 | PI5A23157ZUAEX | 1 | IC19 | PI5A23157ZUAEX_SPDT_SW_10UQFN | Diodes | PI5A23157ZUAEX | Digi-Key | 31-PI5A23157ZUAEXCT-ND | 2 Circuit IC Switch 2:1 15Ohm 10-UQFN (1.5x2) |  |  | 1
32 | LD39100PUR | 4 | IC20, IC25, IC28, IC31 | LD39100PUR | STMicroelectronics | LD39100PUR | Digi-Key | 497-11013-1-ND | Linear Voltage Regulator IC Positive Adjustable Output 0.8 V ~ 4.5 V 1A 6-DFN (3x3) | NF(IC31) | 1 | 3
33 | LP8758A1E0YFFR | 2 | IC21, IC30 | LP8758A1E0YFFR_QUAD_DC-DC_35DSBGA | Texas Instruments | LP8758A1E0YFFR | Digi-Key | 296-47808-1-ND | Buck Switching Regulator IC Positive Programmable 0.5V 4 Output 4A 35-UFBGA, DSBGA |  |  | 2
34 | MAX40200ANS+ | 3 | IC22, IC23, IC27 | MAX40200ANS+_IDEAL_DIODE_4WLP | Maxim | MAX40200ANS+ | Digi-Key | MAX40200ANS+-ND | OR Controller Source Selector Switch P-Channel 1:1 4-WLP (0.73x0.73) |  |  | 3
35 | MAX40203AUK | 3 | IC24, IC26, IC29 | SOT23-5_v1 | Maxim | MAX40203AUK+T | Digi-Key | 175-MAX40203AUK+TCT-ND | OR Controller Source Selector Switch P-Channel 1:1 SOT-23-5 | NF(IC24 IC26 IC29) | 3 | 0
36 | LM4040 | 1 | IC32 | SOT23-3_v3 | Diodes | LM4040C30FTA | Digi-Key | LM4040C30FTADICT-ND | Shunt Voltage Reference IC Fixed 3V V ±0.5% 15 mA SOT-23-3 |  |  | 1
37 | 47nH | 3 | L1, MN53, MN54 | RES0402 | COILCRAFT | 0402HP-47NXJLU | Farnell | 2285856 | INDUCTOR, RF, 47NH, 5%, 2.4GHZ, SMD; Product Range:0402HP Series; Inductance:47nH; Inductance Tolerance:± 5%; High Frequency Inductor Case:0402 [1005 Metric]; Self Resonant Frequency Min:2.4GHz; DC Resistance Max:0.58ohm; DC Current Rating:420mA | NF(MN53 MN54) | 2 | 1
38 | 0.47uH, 4A | 8 | L2, L3, L4, L5, L6, L7, L8, L9 | IND0806 | TDK | VLS201610HBX-R47M-1 | Digi-Key | 445-172395-1-ND | 470 nH Shielded Drum Core, Wirewound Inductor 2.81 A 41mOhm Max 0806 (2016 Metric) |  |  | 8
39 | LED_green | 2 | LED1, LED2 | LED0201 | Kingbright | APG0603CGC-TT | Digi-Key | 754-2021-1-ND | Green 571nm LED Indication - Discrete 1.97V 2-SMD, 0201 |  |  | 2
40 | BMI-S-202-C | 1 | MECH1 | BMI-S-202-C_RF_SHIELD_COVER | Laird | BMI-S-202-C | Digi-Key | 903-1014-ND | RF Shield Cover 0.668" (16.96mm) X 0.668" (16.96mm) Vent Holes in Pattern Snap Fit |  |  | 1
41 | BMI-S-202-F | 1 | MECH2 | BMI-S-202-F_RF_SHIELD_FRAME_v3 | Laird | BMI-S-202-F | Digi-Key | 903-1051-1-ND | RF Shield Frame 0.650" (16.50mm) X 0.650" (16.50mm) Surface Mount |  |  | 1
42 | 10 nH, 5% | 8 | MN1, MN2, MN3, MN4, MN31, MN32, MN47, MN48 | RES0402 | Murata | LQW15AN10NJ00D | Digi-Key | 490-1146-6-ND | RF Inductors - SMD 10 NH 5% | NF(MN31 MN32) | 2 | 6
43 | 10 pF, 50V | 8 | MN5, MN6, MN11, MN12, MN37, MN38, MN43, MN44 | CAP0402 | Walsin Technologies | 0402N100D500CT | Digi-Key | 1292-0402N100D500CT-ND | 10 pF ±0.5pF 50V Ceramic Capacitor C0G, NP0 0402 (1005 Metric) |  |  | 8
44 | 0.5pF | 2 | MN7, MN8 | CAP0402 | Yageo | CC0402CRNPO9BNR50 | Digi-Key | 311-1001-1-ND | 0.50pF ±0.25pF 50V C0G, NP0 Ceramic Capacitor -55°C ~ 125°C Surface Mount, MLCC 0402 (1005 Metric) 0.039" L x 0.020" W (1.00mm x 0.50mm) | NF(MN7 MN8) | 2 | 0
45 | 1pF | 2 | MN9, MN10 | CAP0402 | TDK Corporation | C1005C0G1H010B050BA | Digi-Key | 445-4854-6-ND | 1pF ±0.1pF 50V C0G, NP0 Ceramic Capacitor -55°C ~ 125°C Surface Mount, MLCC 0402 (1005 Metric) 0.039" L x 0.020" W (1.00mm x 0.50mm) | NF(MN9 MN10) | 2 | 0
46 | 100uH | 4 | MN13, MN14, MN15, MN16 | RES0805 | TDK Corporation | MLF2012C101KT000 | Digi-Key | 445-1071-1-ND | FIXED IND 100UH 2MA 3.1 OHM SMD |  |  | 4
47 | 0R | 6 | MN17, MN18, MN19, MN20, R27, R31 | RES0402 | Yageo | RC0402JR-070RL | Digi-Key | 311-0.0JRTR-ND | RES SMD 0.0OHM JUMPER 1/16W 0402 |  |  | 6
48 | 100nF, 16V | 4 | MN21, MN22, MN27, MN28 | CAP0402 | Murata Electronics | GRM155R71C104KA88D | Mouser | 81-GRM155R71C104KA88 | 0.10µF ±10% 16V X7R Ceramic Capacitor -55°C ~ 125°C Surface Mount, MLCC 0402 (1005 Metric) 0.039" L x 0.020" W (1.00mm x 0.50mm) |  |  | 4
49 | 1pF, 50V | 6 | MN23, MN25, MN33, MN34, MN41, MN42 | CAP0402 | TDK Corporation | C1005C0G1H010B050BA | Digi-Key | 445-4854-6-ND | 1pF ±0.1pF 50V C0G, NP0 Ceramic Capacitor -55°C ~ 125°C Surface Mount, MLCC 0402 (1005 Metric) 0.039" L x 0.020" W (1.00mm x 0.50mm) | NF(MN23 MN25 MN33 MN34 MN41 MN42) | 6 | 0
50 | 2pF, 50V | 2 | MN24, MN26 | CAP0402 | AVX | 04025U2R0BAT2A | Farnell | 2332536 | SMD Multilayer Ceramic Capacitor, U Series, 2 pF, ± 0.1pF, C0G / NP0, 50 V, 0402 [1005 Metric] |  |  | 2
51 | 470pF, 50V | 4 | MN29, MN30, MN35, MN36 | CAP0402 | TDK Corporation | C1005C0G1H471J050BA | Digi-Key | 445-2656-6-ND | 470pF ±5% 50V Ceramic Capacitor C0G, NP0 0402 (1005 Metric) |  |  | 4
52 | 0.5pF, 50V | 2 | MN39, MN40 | CAP0402 | Yageo | CC0402CRNPO9BNR50 | Digi-Key | 311-1001-1-ND | 0.50pF ±0.25pF 50V C0G, NP0 Ceramic Capacitor -55°C ~ 125°C Surface Mount, MLCC 0402 (1005 Metric) 0.039" L x 0.020" W (1.00mm x 0.50mm) | NF(MN39 MN40) | 2 | 0
53 | 100pF, 50V | 4 | MN45, MN46, MN51, MN52 | CAP0402 | Yageo | CC0402JRNPO9BN101 | Digi-Key | 311-1024-1-ND | 100pF ±5% 50V C0G, NP0 Ceramic Capacitor -55°C ~ 125°C Surface Mount, MLCC 0402 (1005 Metric) 0.039" L x 0.020" W (1.00mm x 0.50mm) |  |  | 4
54 | 0.8pF | 2 | MN49, MN50 | CAP0402 | Murata Electronics North America | GRM1555C1HR80BA01D | Digi-Key | 490-6269-1-ND | 0.80pF ±0.1pF 50V C0G, NP0 Ceramic Capacitor -55°C ~ 125°C Surface Mount, MLCC 0402 (1005 Metric) 0.039" L x 0.020" W (1.00mm x 0.50mm) |  |  | 2
55 | 0R | 30 | R1, R30, R51, R52, R53, R59, R60, R66, R67, R74, R76, R79, R86, R90, R91, R93, R94, R95, R96, R98, R99, R100, R101, R103, R106, R112, R113, R116, R125, R126 | RES0201 | Yageo | RC0201JR-070RL | Digi-Key | 311-0.0NCT-ND | 0 Ohms Jumper Chip Resistor 0201 (0603 Metric) Moisture Resistant Thick Film | NF(R1 R60 R66 R103 R106 R112 R113 R125) | 8 | 22
56 | 15R, 1% | 12 | R2, R14, R37, R38, R39, R41, R57, R73, R75, R80, R83, R92 | RES0201 | Yageo | RC0201FR-0715RL | Digi-Key | 311-15.0MCT-ND | 15 Ohms ±1% 0.05W, 1/20W Chip Resistor 0201 (0603 Metric) Moisture Resistant Thick Film |  |  | 12
57 | 3k, 1% | 5 | R3, R4, R47, R49, R71 | RES0201 | Yageo | RC0201FR-073KL | Digi-Key | YAG2656CT-ND | 3 kOhms ±1% 0.05W, 1/20W Chip Resistor 0201 (0603 Metric) Moisture Resistant Thick Film | NF(R71) | 1 | 4
58 | 10k, 1% | 18 | R5, R6, R7, R8, R9, R15, R16, R34, R35, R36, R65, R68, R77, R82, R105, R111, R115, R121 | RES0201 | Yageo | RC0201FR-0710KL | Digi-Key | 311-10.0KMCT-ND | 10 kOhms ±1% 0.05W, 1/20W Chip Resistor 0201 (0603 Metric) Moisture Resistant Thick Film | NF(R65 R68 R121) | 3 | 15
59 | 47R, 1% | 6 | R10, R11, R12, R13, R61, R70 | RES0201 | Yageo | RC0201FR-0747RL | Digi-Key | YAG2694CT-ND | 47 Ohms ±1% 0.05W, 1/20W Chip Resistor 0201 (0603 Metric) Moisture Resistant Thick Film |  |  | 6
60 | 100R, 1% | 7 | R17, R18, R19, R20, R40, R64, R124 | RES0201 | Yageo | RC0201FR-07100RL | Digi-Key | 311-100MCT-ND | 100 Ohms ±1% 0.05W, 1/20W Chip Resistor 0201 (0603 Metric) Moisture Resistant Thick Film |  |  | 7
61 | 1k, 1% | 7 | R21, R22, R23, R50, R62, R63, R69 | RES0201 | Yageo | RC0201FR-071KL | Digi-Key | 311-1KMDKR-ND | 1 kOhms ±1% 0.05W, 1/20W Chip Resistor 0201 (0603 Metric) Moisture Resistant Thick Film |  |  | 7
62 | 4.7k, 1% | 8 | R24, R25, R26, R43, R45, R81, R84, R85 | RES0201 | Yageo | RC0201FR-074K7L | Digi-Key | 311-4.70KMCT-ND | 4.7 kOhms ±1% 0.05W, 1/20W Chip Resistor 0201 (0603 Metric) Moisture Resistant Thick Film |  |  | 8
63 | 10R | 4 | R28, R29, R32, R33 | RES0201 | Panasonic Electronic Components | ERJ-1GEF10R0C | Digi-Key | P10.0ABCT-ND | RES SMD 10 OHM 1% 1/20W 0201 |  |  | 4
64 | 330R, 1% | 5 | R42, R44, R78, R97, R102 | RES0201 | Vishay Dale | CRCW0201330RFKED | Digi-Key | 541-330AABCT-ND | 330 Ohms ±1% 0.05W, 1/20W Chip Resistor 0201 (0603 Metric) Thick Film |  |  | 5
65 | 100k, 1% | 3 | R56, R58, R88 | RES0201 | Yageo | RC0201FR-07100KL | Digi-Key | 311-100KMCT-ND | 100 kOhms ±1% 0.05W, 1/20W Chip Resistor 0201 (0603 Metric) Moisture Resistant Thick Film |  |  | 3
66 | 12.7k, 1% | 2 | R72, R114 | RES0201 | Yageo | RC0201FR-0712K7L | Digi-Key | 311-12.7KMCT-ND | 12.7 kOhms ±1% 0.05W, 1/20W Chip Resistor 0201 (0603 Metric) Moisture Resistant Thick Film |  |  | 2
67 | 47k, 1% | 2 | R87, R108 | RES0201 | Yageo | RC0201FR-0747KL | Digi-Key | 311-47KMCT-ND | 47 kOhms ±1% 0.05W, 1/20W Chip Resistor 0201 (0603 Metric) Moisture Resistant Thick Film |  |  | 2
68 | 8.06k, 1% | 1 | R89 | RES0201 | Yageo | RC0201FR-078K06L | Digi-Key | YAG2831CT-ND | 8.06 kOhms ±1% 0.05W, 1/20W Chip Resistor 0201 (0603 Metric) Moisture Resistant Thick Film |  |  | 1
69 | 5.6k, 1% | 1 | R104 | RES0201 | Yageo | RC0201FR-075K6L | Digi-Key | YAG2346CT-ND | 5.6 kOhms ±1% 0.05W, 1/20W Chip Resistor 0201 (0603 Metric) Moisture Resistant Thick Film |  |  | 1
70 | 3k3, 1% | 5 | R107, R109, R117, R118, R119 | RES0201 | Yageo | RC0201FR-073K3L | Digi-Key | YAG2285CT-ND | 3.3 kOhms ±1% 0.05W, 1/20W Chip Resistor 0201 (0603 Metric) Moisture Resistant Thick Film |  |  | 5
71 | 7.5k, 1% | 1 | R110 | RES0201 | Stackpole Electronics | RMCF0201FT7K50 | Digi-Key | RMCF0201FT7K50CT-ND | 7.5 kOhms ±1% 0.05W, 1/20W Chip Resistor 0201 (0603 Metric) Thick Film |  |  | 1
72 | 31.6k, 1% | 1 | R120 | RES0201 | Yageo | RC0201FR-0731K6L | Digi-Key | YAG2597CT-ND | 31.6 kOhms ±1% 0.05W, 1/20W Chip Resistor 0201 (0603 Metric) Moisture Resistant Thick Film | NF(R120) | 1 | 0
73 | 3600BL14M050 | 4 | T1, T2, T7, T8 | 3600BL14M050_balun_0603 | Johanson | 3600BL14M050T | Digi-Key | 712-1048-1-ND | Signal Conditioning 3.6GHz 1:1 BALUN |  |  | 4
74 | TC1-1-13M-45+ | 4 | T3, T4, T9, T10 | TC1-1-13MA+_JA4220-AL_ | Minicircuits | TC1-1-13M-45+ | Minicircuits | TC1-1-13M-45+ | RF balun; 1:1 ratio; 3 dB bandwidth: 0.3 MHz to 3.5 GHz; 3.8mm x 3.8mm |  |  | 4
75 | B0322J5050AHF | 2 | T5, T6 | Anaren_0805_balun_B0322J5050AHF | Anaren | B0322J5050AHF | Mouser | 620-B0322J5050AHF | Signal Conditioning 300-2200MHz 50 Ohm IL=1.6dB |  |  | 2
76 | U.FL/MMCX | 7 | X1, X2, X3, X4, X5, X6, X7 | MMCX_UFL_conn_u_v2 | Molex, LLC | 0734120110 | Digi-Key | WM5587CT-ND | Ultra Miniature Coaxial Connector Receptacle, Male Pin 50 Ohm Surface Mount Solder |  |  | 7
77 | 5025981593 | 2 | X8, X13 | 5025981593_FPC_connector | Molex | 5025981593 | Digi-Key | 900-5025981593CT-ND | 15 Position FPC Connector Contacts, Top and Bottom 0.012" (0.30mm) Surface Mount, Right Angle |  |  | 2
78 | Molex 0788641001 | 1 | X9 | Molex_0788641001_spring_contacts | Molex | 78864-1001 | Digi-Key | WM11204CT-ND | 6 Position Spring Battery Contact Connector Surface Mount | NF(X9) | 1 | 0
79 | USB Micro Type B | 1 | X11 | USB_Micro_TypeB_47346-0001 | Molex | 47346-0001 | Digi-Key | WM17141CT-ND | USB - micro B USB 2.0 Receptacle Connector 5 Position Surface Mount, Right Angle |  |  | 1
80 | 8-pin FPC connector | 1 | X12 | 503480-0800_8PIN_FPC_CONN | Molex | 503480-0800 | Digi-Key | WM1388CT-ND | 8 Position FFC, FPC Connector Contacts, Top and Bottom 0.020" (0.50mm) Surface Mount, Right Angle |  |  | 1
81 | E6982LF | 1 | XO1 | RAKON_E8231LF_E6982LF | Rakon | E6982LF | Rakon | E6982LF | 26MHz E6982LF Small Cell TCVCXO, w EN and VC, L x W: 5.0 x 3.2 mm nom., H: 2.1 mm max. (6 pad) |  |  | 1
 |  |  |  |  |  |  |  |  |  |  |  | Total NF element number: 47
 |  |  |  |  |  |  |  |  |  |  |  | All NF elements in one row:
 |  |  |  |  |  |  |  |  |  |  |  | NF(C194 C204 C210 C219 C170 C223 ESD1 ESD2 ESD3 ESD4 ESD5 IC2 IC13 IC31 IC24 IC26 IC29 MN53 MN54 MN31 MN32 MN7 MN8 MN9 MN10 MN23 MN25 MN33 MN34 MN41 MN42 MN39 MN40 R1 R60 R66 R103 R106 R112 R113 R125 R71 R65 R68 R121 R120 X9)
 |  |  |  |  |  |  |  |  |  |  |  | *NOTE: NF(R1 R2) means that elements R1 and R2 are unpopulated (NF)

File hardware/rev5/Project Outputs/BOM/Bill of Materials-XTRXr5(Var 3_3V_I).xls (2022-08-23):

Description | Comment | Value | Tolerance | U/P/TKE | Misc | Footprint | LibRef | Designator | Link | Manufacturer | Quantity
Artix-7 FPGA | XC7A35T-2CPG236I |  |  |  |  | CPG236 | XC7A35T-2CPG236C | U1 |  | Xilinx | 1
Balun | JA4220-AL |  |  |  | RF 1:1 Balun 50 Ohm, h 3mm | JA4220-AL | Balun JA4220-AL | T2, T4, T7, T10 | https://octopart.com/ja4220-al-coilcraft-30564806 | Coilcraft | 4
Balun bal-unbal | 3600BL14M050 | 3600BL14M050 |  |  |  | Balun 1.6x0.8x0.6mm | Balun 3-4GHz | T1, T3, T6, T9 | https://octopart.com/3600bl14m050t-johanson-11760610 | Johanson Technology, Inc. | 4
Balun bal-unbal | ATB2012E-50011M-T01 | ATB2012E-50011M-T01 |  |  |  | Balun 1.2x2x1mm | Balun ATB2012 | T5, T8 | https://octopart.com/atb2012e-50011m-t01-tdk-38835046 | TDK | 2
Capacitor | 0.01uF | 0.01uF | 10% | X7R |  | C0402-cirq | C0402 | C30, C31 | https://octopart.com/search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 | Any | 2
Capacitor | 0.1uF | 0.1uF | 20% | X7R 16V |  | C0402-cirq | C0402 | C6, C7, C9, C10, C13, C17, C18, C21, C27, C36, C42, C44, C45, C58, C59, C60, C61, C131, C132, C167, C168, C169, C170, C183, C184, C191, C192, C215, C216, C220 | https://octopart.com/search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 | Any | 30
Capacitor | 0.22uF | 0.22uF | 20% | X5R 16V |  | C0402-cirq | C0402 | C32, C33, C34, C35, C38, C39, C40, C41 | https://octopart.com/search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 | Any | 8
Capacitor | 0.47uF | 0.47uF | 20% | X5R 16V |  | C0402-cirq | C0402 | C127, C128, C129, C136, C137, C138, C139, C142, C143, C144, C145, C149, C150, C151, C152, C155, C156, C157, C158, C162, C163, C165 | https://octopart.com/search?avg_avail=(1__*)&q=x5r%200.47uf%200402&r=sp&s=NUEPno7bQ4qfu1XPud9uDg&start=0 | Any | 22
Capacitor | 1uF | 1uF | 20% | X5R 10V |  | C0402-cirq | C0402 | C1, C2, C3, C4, C5, C8, C11, C15, C16, C29, C37, C74, C75, C76, C82, C83, C84, C85, C86, C87, C88, C89, C90, C91, C92, C93, C94, C95, C96, C97, C98, C99, C100, C101, C102, C103, C104, C105, C106, C107, C108, C109, C110, C111, C112, C113, C114, C115, C116, C122, C219 | https://octopart.com/search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 | Any | 51
Capacitor | 2pF | 2pF | 10% | C0G 50V |  | C0402-cirq | C0402 | C171, C172 | https://octopart.com/search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 | Any | 2
Capacitor | 4.7uF | 4.7uF | 20% | X5R 6.3V |  | C0402-cirq | C0402 | C20, C54, C55, C56, C57, C62, C63, C64, C65, C77, C117, C125, C126, C130, C134, C135, C140, C141, C147, C148, C153, C154, C161, C164, C166 | https://octopart.com/search?avg_avail=(1__*)&q=4.7uf%200402&start=0&specs2.76.numbers=4.7e-06 | Any | 25
Capacitor | 10pF | 10pF | 20% | C0G 50V |  | C0402-cirq | C0402 | C23, C25, C176, C177, C180, C181, C193, C194, C203, C204, C209, C210 | https://octopart.com/search?avg_avail=(1__*)&q=10pF%20%20C0G%20NP0%20%2050V%200402&start=0 | Any | 12
Capacitor | 10uF | 10uF | 20% | X5R 6.3V |  | C0603-Phillips | C0603 | C46, C47, C48, C49, C50, C51, C52, C53 | https://octopart.com/search?avg_avail=(1__*)&q=10uF%20%20x5r%206.3v%200603&start=0 | Any | 8
Capacitor | 47uF | 47uF | 20% | X5R 4V, X5R 6.3V |  | C0603 tall | C0603-TALL | C43, C66, C67, C68, C69, C70, C71, C72, C73, C123, C124, C133, C146, C159, C160 | https://octopart.com/zrb18ar60j476me01l-murata-71221023?r=sp&s=AX1jIhZnRzqCJDNKo8E3Og | MuRata | 15
Capacitor | 100pF | 100pF | 20% | C0G 50V |  | C0402-cirq | C0402 | C22, C189, C190, C205, C206, C211, C212, C217, C218 | https://octopart.com/search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 | Any | 9
Capacitor | 470pF | 470pF | 20% | NP0 50V |  | C0402-cirq | C0402 | C175, C178, C179, C182, C201, C202, C207, C208 | https://octopart.com/search?avg_avail=(1__*)&q=470pF%20%20C0G%20NP0%20%2050V%200402&start=0 | Any | 8
Capacitor | 1000pF | 1000pF | 10% | C0G NP0 |  | C0402-cirq | C0402 | C12, C14, C19, C24, C26, C28, C78, C79, C80, C81, C118, C119, C120, C121 | https://octopart.com/search?avg_avail=(1__*)&q=1000PF%20C0G%20NP0%200402&start=0 | Any | 14
Coil | 0.47uH | 0.47uH |  | 2.8A/35mOhm |  | L-VLS201610HBX | L-VLS20161xHBX-1 | L8, L13, L14, L15, L16, L17, L18, L19, L20 | https://octopart.com/vls201610hbx-r47m-1-tdk-52458594 | TDK | 9
Coil wire wound | 10nH | 10nH | ±5% |  |  | COIL0402-Phillips | L-LQW15 | L63, L64, L65, L66 | https://octopart.com/lqw15an10nj00d-murata-387450 | MuRata | 4
Coil wire wound | 47nH | 47nH | ±5% |  |  | COIL0402-Phillips | L-LQW15 | L4, L5, L6 | https://octopart.com/lqw15an47nj00d-murata-387459 | MuRata | 3
Coil wire wound | 100nH | 100nH | ±5% |  |  | COIL0402-Phillips | L-LQW15 | L59, L60, L61, L62 | https://octopart.com/lqw15anr10j00d-murata-387640 | MuRata | 4
Connector (UMCC) |  | 734120110 |  |  |  | U_FL | U_FL | X1, X2, X3, X4, X5, X6, X7 | https://octopart.com/0734120110-molex-16756629 | Molex | 7
Connector FFC/FPC | 502598-1593 | RxADC, TxDAC |  | 0.3A/50Vrms/-40~+105°C | Connector FFC/FPC 15pin side entry | Molex 502598-1593 | Conn Molex 502598-1593 | X8, X13 | https://octopart.com/502598-1593-molex-71801460 | Molex | 2
Connector FFC/FPC | 503480-0800 | GPIO |  | 0.5A/50Vrms/-40~+85°C | Connector FFC/FPC 8pin side entry | Molex 503480-0800 | Conn Molex 503480-0800 one | X12 | https://octopart.com/5034800800-molex-18597066 | Molex | 1
Connector microUSB-B | USB-microB | 47346-0001 |  |  |  | USB-microB | USB-microB | X11 | https://octopart.com/47346-0001-molex-7164928 | Molex | 1
ESD diod unidirectional | SESD0402S-005-054 |  |  | 5.4V |  | SESD0402-Phillips | SESD0402S | ESD1 | https://octopart.com/search?q=SESD0402S-005-054 | Tyco Electronics Corp | 1
Ferrite bead EMIFIL | 220 | 220 |  |  |  | BEAD0402-Phillips | EMI BLM15 | L1, L2, L3, L7, L9, L10, L11, L12, L21, L22, L23, L24, L25, L26, L27, L28, L29, L30, L31, L32, L33, L34, L35, L36, L37, L38, L39, L40, L41, L42, L43, L44, L45, L46, L47, L48, L49, L50, L51, L52, L53, L54, L55, L56, L57, L58, L71, L72, L73, L74 | https://octopart.com/blm15eg221sn1d-murata-368376 | MURATA | 50
FPRF MIMO Transceiver IC | LMS7002M |  |  |  | Multi-band Multi-standard Transceiver with Digital Interface | aQFN260(11.5x11.5mm) | LMS7002M | U2 |  | Lime Microsystems | 1
IC | LP5900TLX-3.0/NOPB |  |  |  | Ultra Low Noise LDO | BGA DSBGA-4 | LP5900TL | U9 | https://octopart.com/search?q=LP5900TLX-3.0&start=0 | TI | 1
IC 4xDC/DC | LP8758A1E0YFFR |  |  | 2.5-5.5V to 0.5-3.3V | 4x 4A DC/DCs, i2c control | BGA WLCSP35 | LP8758-E0 | U19, U20 | https://octopart.com/lp8758a1e0yffr-texas+instruments-68058967 | TI | 2
IC dual LDO extra low noise | TPS7A8801RTJT |  |  | 1.4-6.5V/Vdo<0.2V/NF<3.8uVrms |  | QFN-20(4X4/0.5)TI | TPS7A88 | U21, U22 | https://octopart.com/tps7a8801rtjt-texas+instruments-68059618 | TI | 2
IC dual SPDT bi-dir switch | FSA2257L10X |  |  | 1.65-5.5V/3dB@200MHz | Analog SPDT Low R switch dual 1:2 | MICROPAK-10(2.1X1.6P0.5) | FSA2257L10X | U30 | https://octopart.com/fsa2257l10x-on+semiconductor-84328207 | Fairchild | 1
IC ideal diode switch | MAX40200ANS+ | MAX40200ANS+ |  | 1.5-5.5V/1A | IC ideal diode switch | BGA WLP4 (0.7x0.7/0.35) | MAX40200ANS+ | U15, U16, U17, U27, U28, U29 | https://octopart.com/max40200ans%2Bt-maxim+integrated-80998950 | MAXIM | 6
IC NOR FLASH | MT25QL256ABA8E12 |  |  | 2.7-3.3V |  | BGA T-BGA25 (6X8/1.0) | MT25QL(U)256_BGA-12 | U4 | https://octopart.com/search?q=MT25QL256ABA8E12 | Micron | 1
IC NOR FLASH | MT25QL256ABA8E14 |  |  | 2.7-3.3V |  | BGA T-BGA24 (6X8/1.0) | MT25QL(U)256_BGA-14 | U4' | https://octopart.com/search?q=MT25QL256ABA8E14 | Micron | 1
IC RF SP4T Switch | SKY13414-485LF |  |  | Vcc 2.5-4.8V/Vcont 1.35-2.7V | SP4T 0.1-3.8 GHz RF Switch, No caps | QFN14(2x2/0.4-0.45) | SKY13414-485LF | U25, U26 | https://octopart.com/search?q=SKY13414-485LF | Skyworks | 2
IC RF Switch | SKY13330-397LF |  |  | 2.3-4.8V | SP4T 0.-6 GHz RF Switch | QFN12(2x2/0.5) | SKY13330-397LF | U23, U24 | https://octopart.com/sky13330-397lf-skyworks+solutions-19662969 | Skyworks | 2
IC serial DAC | PDAC80501MDQFT |  |  |  | SPI/I2C 16-Bit DAC | PWSON8 no PAD | DAC80501 | U5 | https://octopart.com/pdac80501mdqft-texas+instruments-97302471 | TI | 1
IC SIM Card buffer | NCN4555MNR2G |  |  |  |  | QFN16(3x3/0/5mm)-Case485AE | NCN4555MN | U11 | https://octopart.com/ncn4555mnr2g-on+semiconductor-712660 | ON Semi | 1
IC SPDT switch | 74LVC1G3157FZ4 |  |  |  | 1:2 Multiplexer, analog SPDT switch. | X2-DFN1410-6(1.4x1/0.5mm) | 74LVC1G3157 | U12 | https://octopart.com/74lvc1g3157fz4-7-diodes+inc.-73278608 | Diodes | 1
IC Thermosensor | TMP108AIYFF |  |  |  | IC temperature sensor I2C, DSBGA-6 | BGA WCSP6 | TMP108 | U6 | https://octopart.com/tmp108aiyffr-texas+instruments-28946339 | TI | 1
IC Triple Buffer | NC7NP34L8X |  |  | Vcc 0.9-3.6V |  | Micro pak 8 (1.6x1.6/0.5) | NC7NP34L8X | U10 | https://octopart.com/nc7np34l8x-fairchild+semiconductor-425659 | Fairchild | 1
IC USB 2.0 FHY | USB3333E-GL |  |  |  | USB 2.0 FHY ULPI BGA | BGA WLCSP25 | USB3333E-GL | U3 | https://octopart.com/usb3333e-gl-tr-microchip-24995478 | Microchip | 1
LED GREEN | LTST-C190KGKT |  |  | 40mcd, 2V/20mA, -30+85°C | GREEN | LED-0603GR | LED0603GR_Lite-On | LED1, LED2 | https://octopart.com/ltst-c190kgkt-lite-on-549897 | Lite-On Inc | 2
Module GPS resceiver | M10578-A2 |  |  |  | GPS receiver module (A2 opt) | GPS_M10578-Ax | GPS_M10578-Ax | U13 | https://octopart.com/m10578-a2-antenova-71069728?r=sp&s=Oh_j1oz0Summ533Nx3cPvA | Radionova (Antenova) | 1
Resistor | 0 | 0 | 5% | 50V/60mW/200ppm |  | R0402-Phillips | R0402 | R6, R26, R76, R77, R78 |  | BOURNS | 5
Resistor | 1k | 1k | 5% | 50V/60mW/200ppm |  | R0402-Phillips | R0402 | R38, R39, R40, R45, R46, R47 |  | BOURNS | 6
Resistor | 1k2 | 1k2 | 5% | 50V/60mW/200ppm |  | R0402-Phillips | R0402 | R68, R70, R71, R74 |  | BOURNS | 4
Resistor | 1k6 | 1k6 | 5% | 50V/60mW/200ppm |  | R0402-Phillips | R0402 | R67, R72 |  | BOURNS | 2
Resistor | 3k | 3k | 5% | 50V/60mW/200ppm |  | R0402-Phillips | R0402 | R36 |  | BOURNS | 1
Resistor | 3k3 | 3k3 | 5% | 50V/60mW/200ppm |  | R0402-Phillips | R0402 | R34, R61, R62, R64, R65, R66, R69 |  | BOURNS | 7
Resistor | 4k7 | 4k7 | 5% | 50V/60mW/200ppm |  | R0402-Phillips | R0402 | R12, R13, R14, R25, R29, R30, R31, R32, R48, R49, R50, R85 |  | BOURNS | 12
Resistor | 8k06 | 8k06 | 0.50% | 50V/60mW/100ppm |  | R0402-Phillips | R0402 | R9 | https://octopart.com/erj-2rkf8061x-panasonic-55421298 | Panasonic | 1
Resistor | 10 | 10 | 5% | 50V/60mW/200ppm |  | R0402-Phillips | R0402 | R75, R79 |  | BOURNS | 2
Resistor | 10k | 10k | 5% | 50V/60mW/200ppm |  | R0402-Phillips | R0402 | R8, R24, R27, R33 |  | BOURNS | 4
Resistor | 10k 1% | 10k 1% | 1% | 50V/60mW/200ppm |  | R0402-Phillips | R0402 | R1 |  | BOURNS | 1
Resistor | 15 | 15 | 5% | 50V/60mW/200ppm |  | R0402-Phillips | R0402 | R2, R3, R10, R11, R16, R17, R18, R20, R21, R22, R23 |  | BOURNS | 11
Resistor | 20k | 20k | 5% | 50V/60mW/200ppm |  | R0402-Phillips | R0402 | R7 |  | BOURNS | 1
Resistor | 47 | 47 | 5% | 50V/60mW/200ppm |  | R0402-Phillips | R0402 | R15, R80 |  | BOURNS | 2
Resistor | 47k | 47k | 5% | 50V/60mW/200ppm |  | R0402-Phillips | R0402 | R37, R59, R63 |  | BOURNS | 3
Resistor | 100 | 100 | 5%, 1% | 50V/60mW/200ppm |  | R0402-Phillips | R0402 | R4, R5, R58, R81, R82, R83, R84 |  | BOURNS | 7
Resistor | 100k | 100k | 5% | 50V/60mW/200ppm |  | R0402-Phillips | R0402 | R41, R42, R60 |  | BOURNS | 3
Resistor | 330 | 330 | 5% | 50V/60mW/200ppm |  | R0402-Phillips | R0402 | R28, R35, R43, R44, R54 |  | BOURNS | 5
Resistor | 680 | 680 | 5% | 50V/60mW/200ppm |  | R0402-Phillips | R0402 | R73 |  | BOURNS | 1
Screening shield cover | Screening shield cover BMI-S-202-C |  |  |  |  |  | Screen cover BMI-S-202-C | Cover1 | https://octopart.com/bmi-s-202-c-laird-19008953 | Laird Tech | 1
Screening shield frame | Screening shield frame BMI-S-202-F |  |  |  |  | BMI-S-202-F | Screen frame BMI-S-202-F | Shield1 | https://octopart.com/bmi-s-202-f-laird-19008954 | Laird Tech | 1
TCVCXO | TCD4029-26.0M |  |  | 2.5-3.3V/ClippedSIN/0,2ppm |  | TCXO5X3.2 | TCVCXO_5x3.2 | U7 |  | Pletronics | 1

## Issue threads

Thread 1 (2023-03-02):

PCB SPECS

guet-clg, 2023-03-02:
Must IT-180A be used for PCB materials? Can I use FR4?

Must the ink be halogen-free, and can it be replaced by others?

guet-clg, 2023-03-03:
Can you help me?

ztamosevicius, 2023-03-06:
It is not mandatory to use IT-180A, any laminate which has a low loss tangent and a similar dielectric constant can be used. Plain FR4 is not the best option as the weave of the laminate and the loses might not be best suited for RF operation (especially in the 2 GHz and above region). In any case, if changing the material or thickness, controlled impedance trace widths might need to be tweaked for the target impedance (provided in the table in Mechanical 1 layer).

The ink type doesn't matter.

Closed 2023-03-06.

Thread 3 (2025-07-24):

Documentation Inconsistencies between mPCIe schematic and Socket description

cottonnj, 2025-07-24:
Hi Lime team,
I'm connecting a Raspberry Pi Compute Module 5 (CM5) to a LimeSDR XTRX using the open-source LimePSB-RP/CM_V1.4 schematic. While reviewing the schematic against the LimeSDR XTRX mPCIe documentation https://limepsb-rpcm.myriadrf.org/v1.4/#mini-pcie-x1-socket, and I came across a few points that could use clarification.  There seems to be a few inconsistencies.
________________________________________
Pin 7 – CLKREQ#
•	Schematic: Connected to a net labeled PCIe_LCK_nREQ.
•	Documentation: Indicates CLKREQ# should be pulled low (typically with a 330Ω resistor) to enable PCIe clocking.  The Lime XTRX documentation says it is Not connected but the schematic shows it connected.
•	Question: Does the XTRX pull this line low internally, or do I need to add an external pull-down to enable the clock on the CM5?
________________________________________
Pin 17 – TDD_GPIO3_N (TX Enable)
	Documentation: No connection
•	Schematic: Routed to an FPGA on the carrier board.
•	Question: Does this pin need to be driven high or low to enable transmission from the XTRX, or can it safely be left unconnected?  Is it an input or an output of the XTRX?
________________________________________
Pin 19 – CLK_IN (External 3.3V Clock Input)
•	Schematic: Input from the external clock system.
•	Question: Is this input required in all use cases, or can it remain unconnected during normal operation?
________________________________________
Pins 11 and 13 – REFCLK- / REFCLK+
•	Schematic: Connected directly from the CM5 to the XTRX.
•	Note: The CM5 datasheet notes that these signals are “no longer capacitively coupled.”
•	Question: Does this mean I now need to add external AC-coupling capacitors, or does the CM5 include them and I should avoid adding capacitors?  I think the wording is slightly confusing.
________________________________________
Pins 23 and 25 – RPI_PCIE_RX_P / RPI_PCIE_RX_N
Schematic: Connected directly from the CM5 to the XTRX labeled as RX but Schematic labels the them as TX on the XTRX.
•	Question: It appears RX should go to TX but the exact paring of which RX to which TX is not completely clear.  I assume the schematic is correct in this scenario.

________________________________________
Pin 28 – 1.5V
•	Schematic: Connected to a 1.5V regulator.
•	Documentation: Indicates this pin is not connected but is a default for mPCIE.
•	Question: Is this input required by the LimeSDR XTRX, or is it safe to leave it floating and skip the 1.5V supply if I am not planning on using the mPCIE for other things?
________________________________________
Pin 30 & 32 – SMB_DATA & SMB_CLK (I2C Data & Clock)
•	Schematic: Connected to GPIOs on the Raspberry Pi CM5, seemingly used as an I2C bus.
•	Question: Does the LimeSDR XTRX require I2C (or SMBus) communication for basic functionality, or are these optional features?
________________________________________
Pin 31 & 33  – PETn0 (PCIe RX-)
•	Schematic: Connected to Raspberry Pi PCIe TX- (Pin24).  Also in the “Clock diagram V1.4” Pin 31 PCIE_PETn0 appears to be connected to a series of switches and to the FPGA.
•	Documentation: Shows this pin as RX- on the LimeSDR side and connecting to pin 28 on the PI.
•	Question: Is this a mistake in the schematic, or is there an inconsistency in the documentation?  Where should it be connected? I assume RX on PCIE needs to go to TX on the RPI?
________________________________________
Pin 33 – PETp0 (PCIe RX+)
•	Schematic: Connected to Raspberry Pi PCIe TX+.
•	Documentation: Shows this pin as RX+ on the LimeSDR side.
•	Question: Same as Pin 31 — is this reversed in the schematic, or is the documentation inaccurate?
________________________________________
Thanks in advance for your help. I just want to confirm these details before committing to hardware.

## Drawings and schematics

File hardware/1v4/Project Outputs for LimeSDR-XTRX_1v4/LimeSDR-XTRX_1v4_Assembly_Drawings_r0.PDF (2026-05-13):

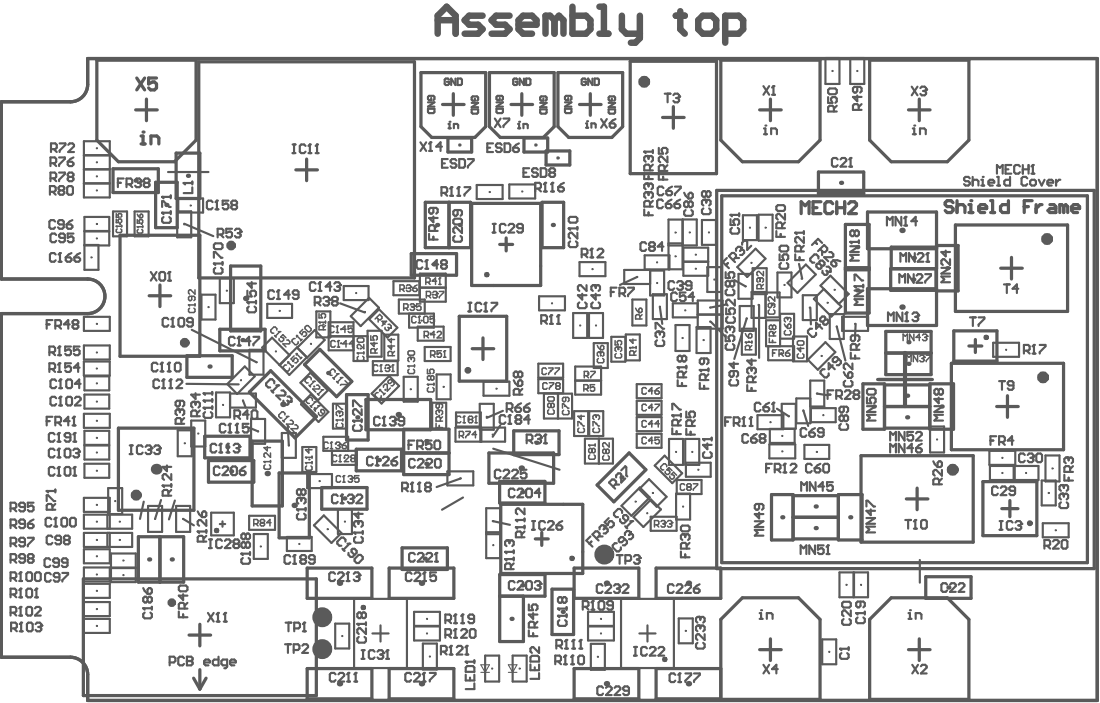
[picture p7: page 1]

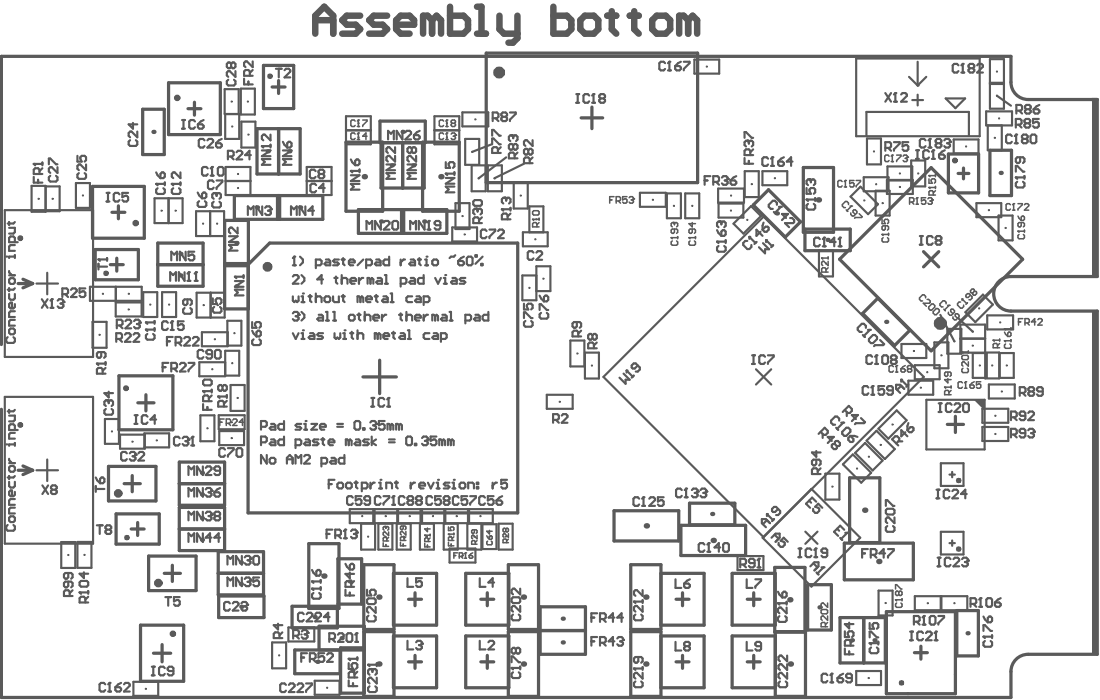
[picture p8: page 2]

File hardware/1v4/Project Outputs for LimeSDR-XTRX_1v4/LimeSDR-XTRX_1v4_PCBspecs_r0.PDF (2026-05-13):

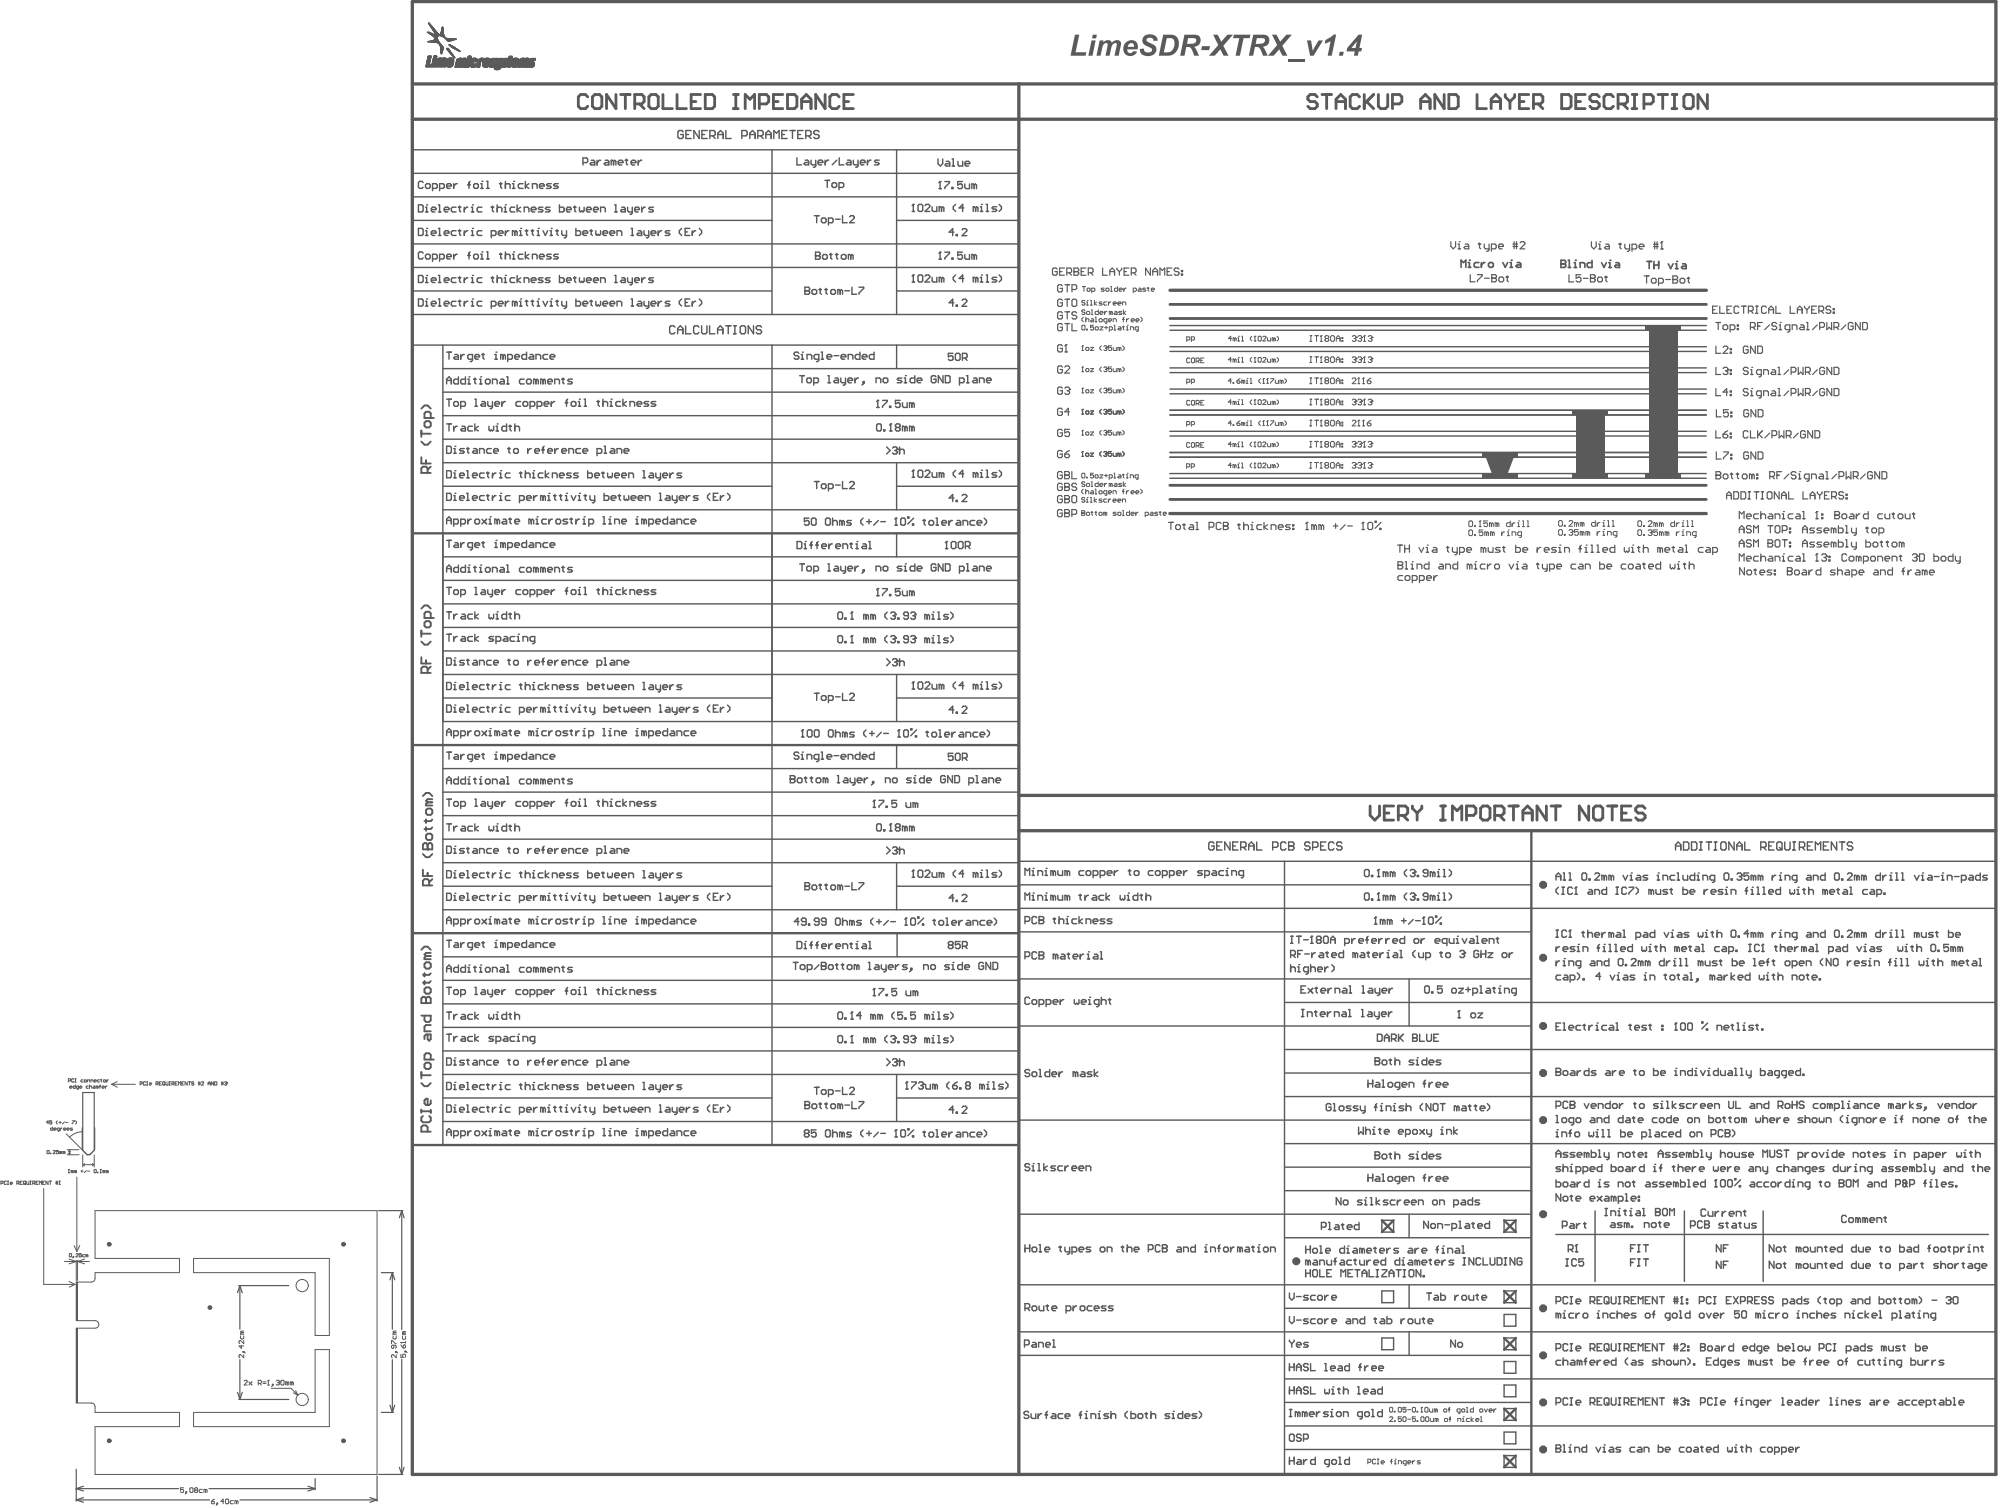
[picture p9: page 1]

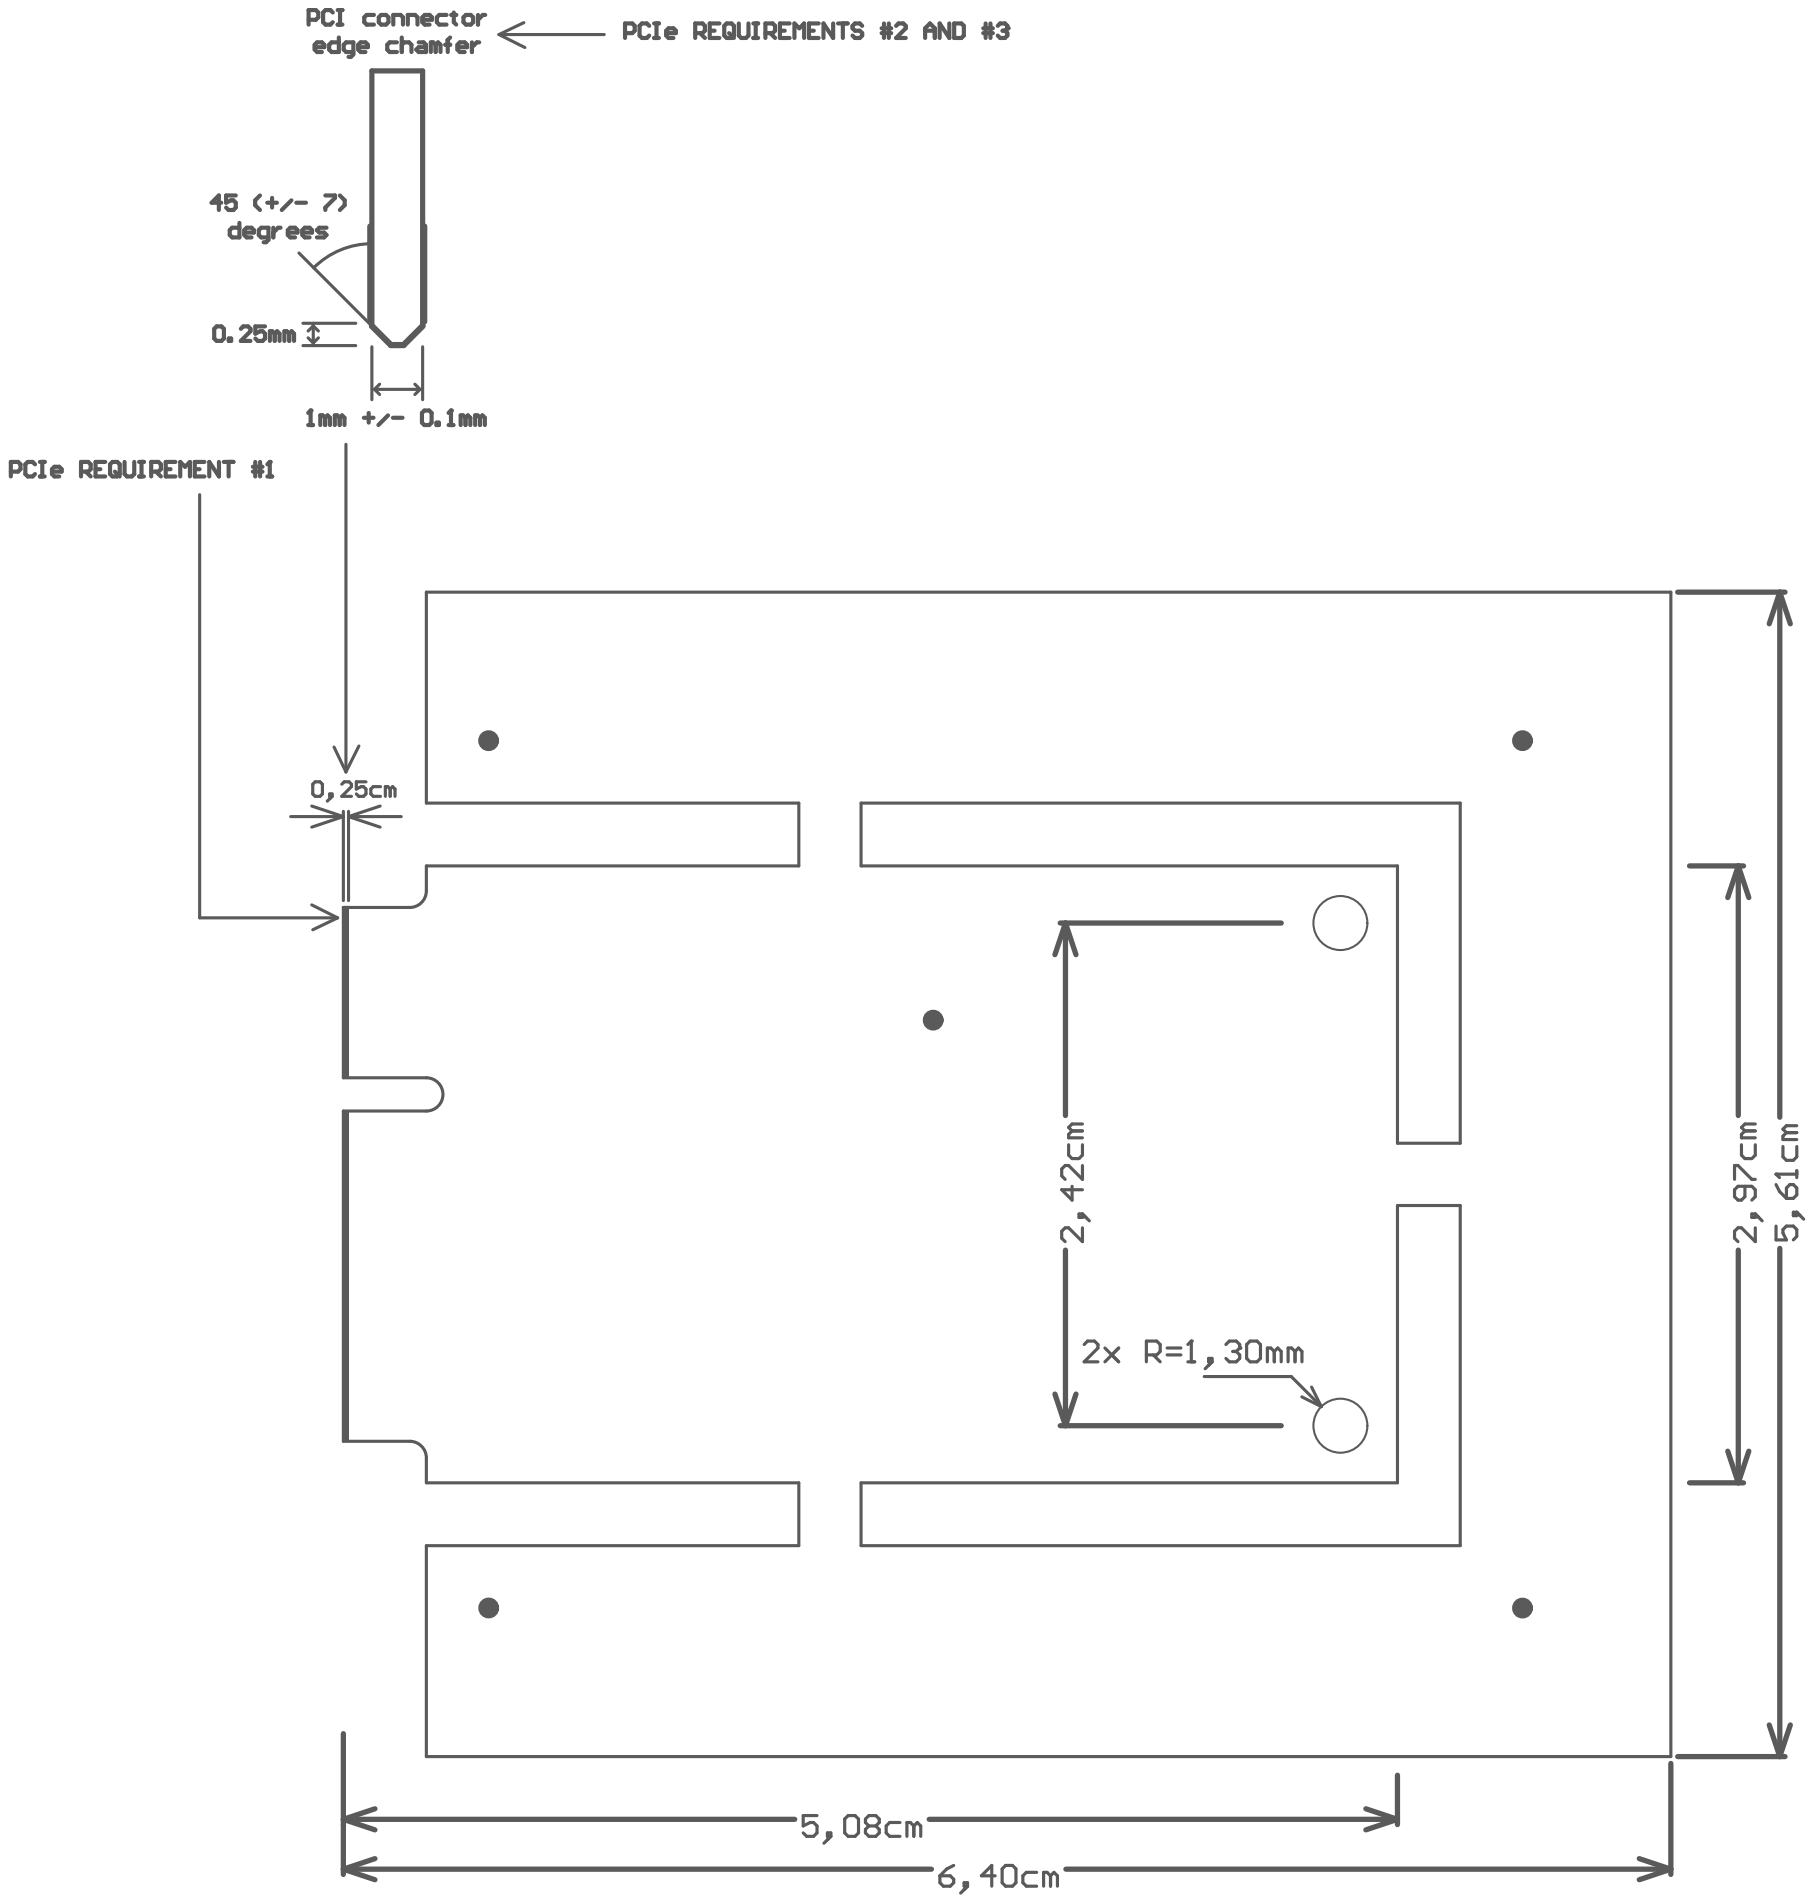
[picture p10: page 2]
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

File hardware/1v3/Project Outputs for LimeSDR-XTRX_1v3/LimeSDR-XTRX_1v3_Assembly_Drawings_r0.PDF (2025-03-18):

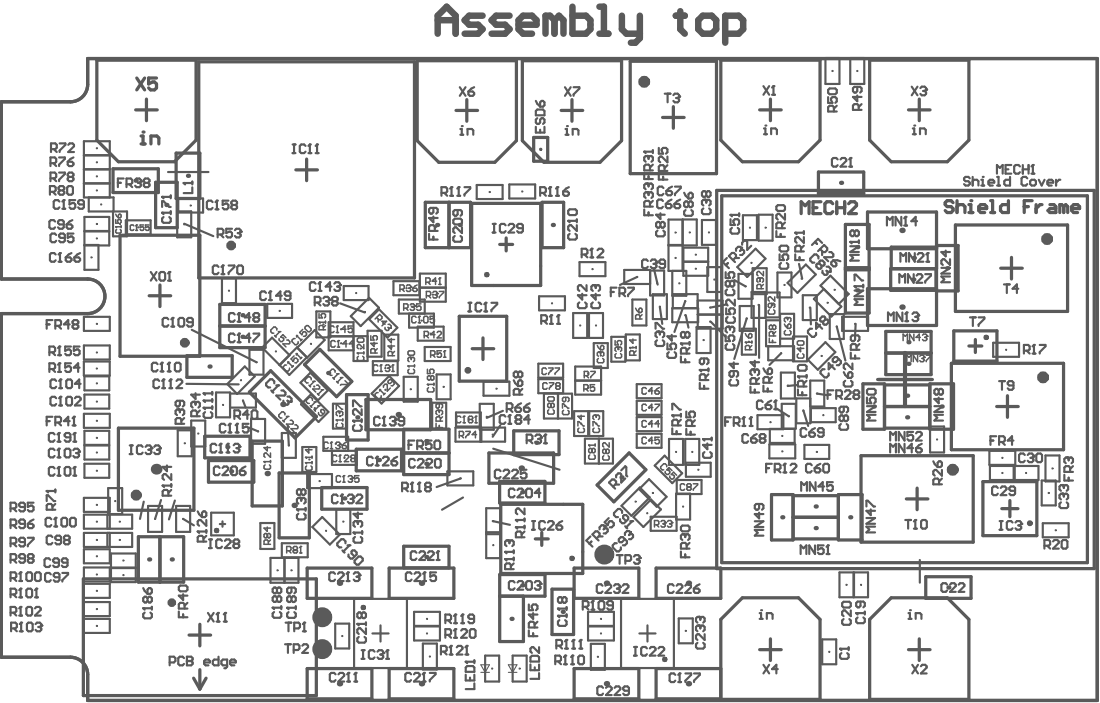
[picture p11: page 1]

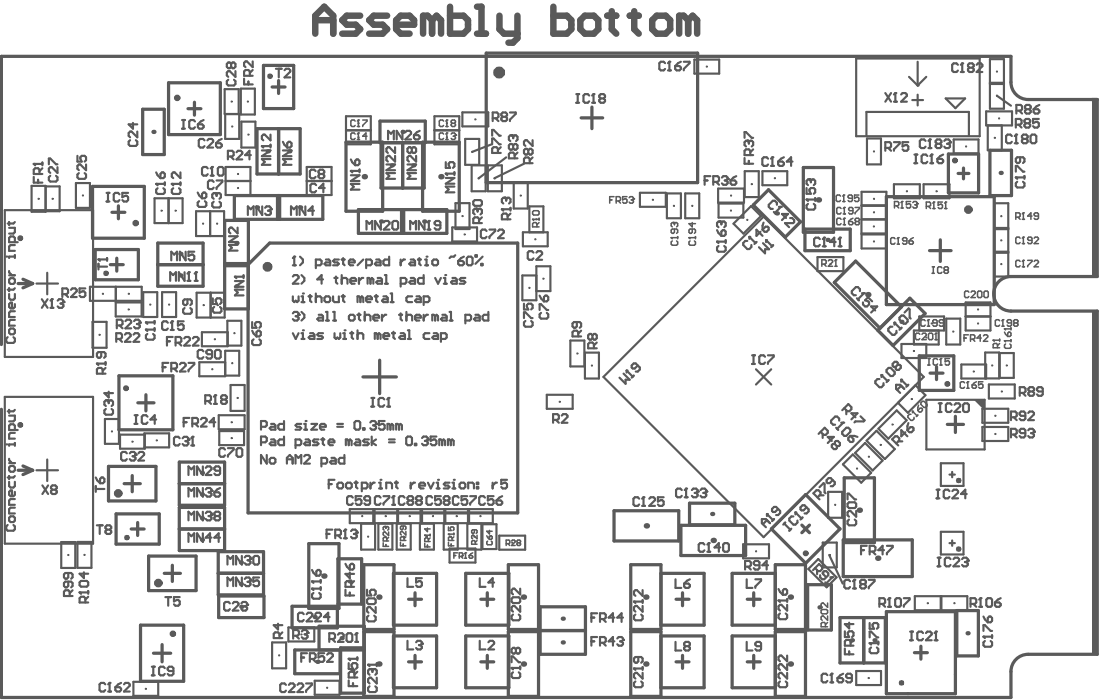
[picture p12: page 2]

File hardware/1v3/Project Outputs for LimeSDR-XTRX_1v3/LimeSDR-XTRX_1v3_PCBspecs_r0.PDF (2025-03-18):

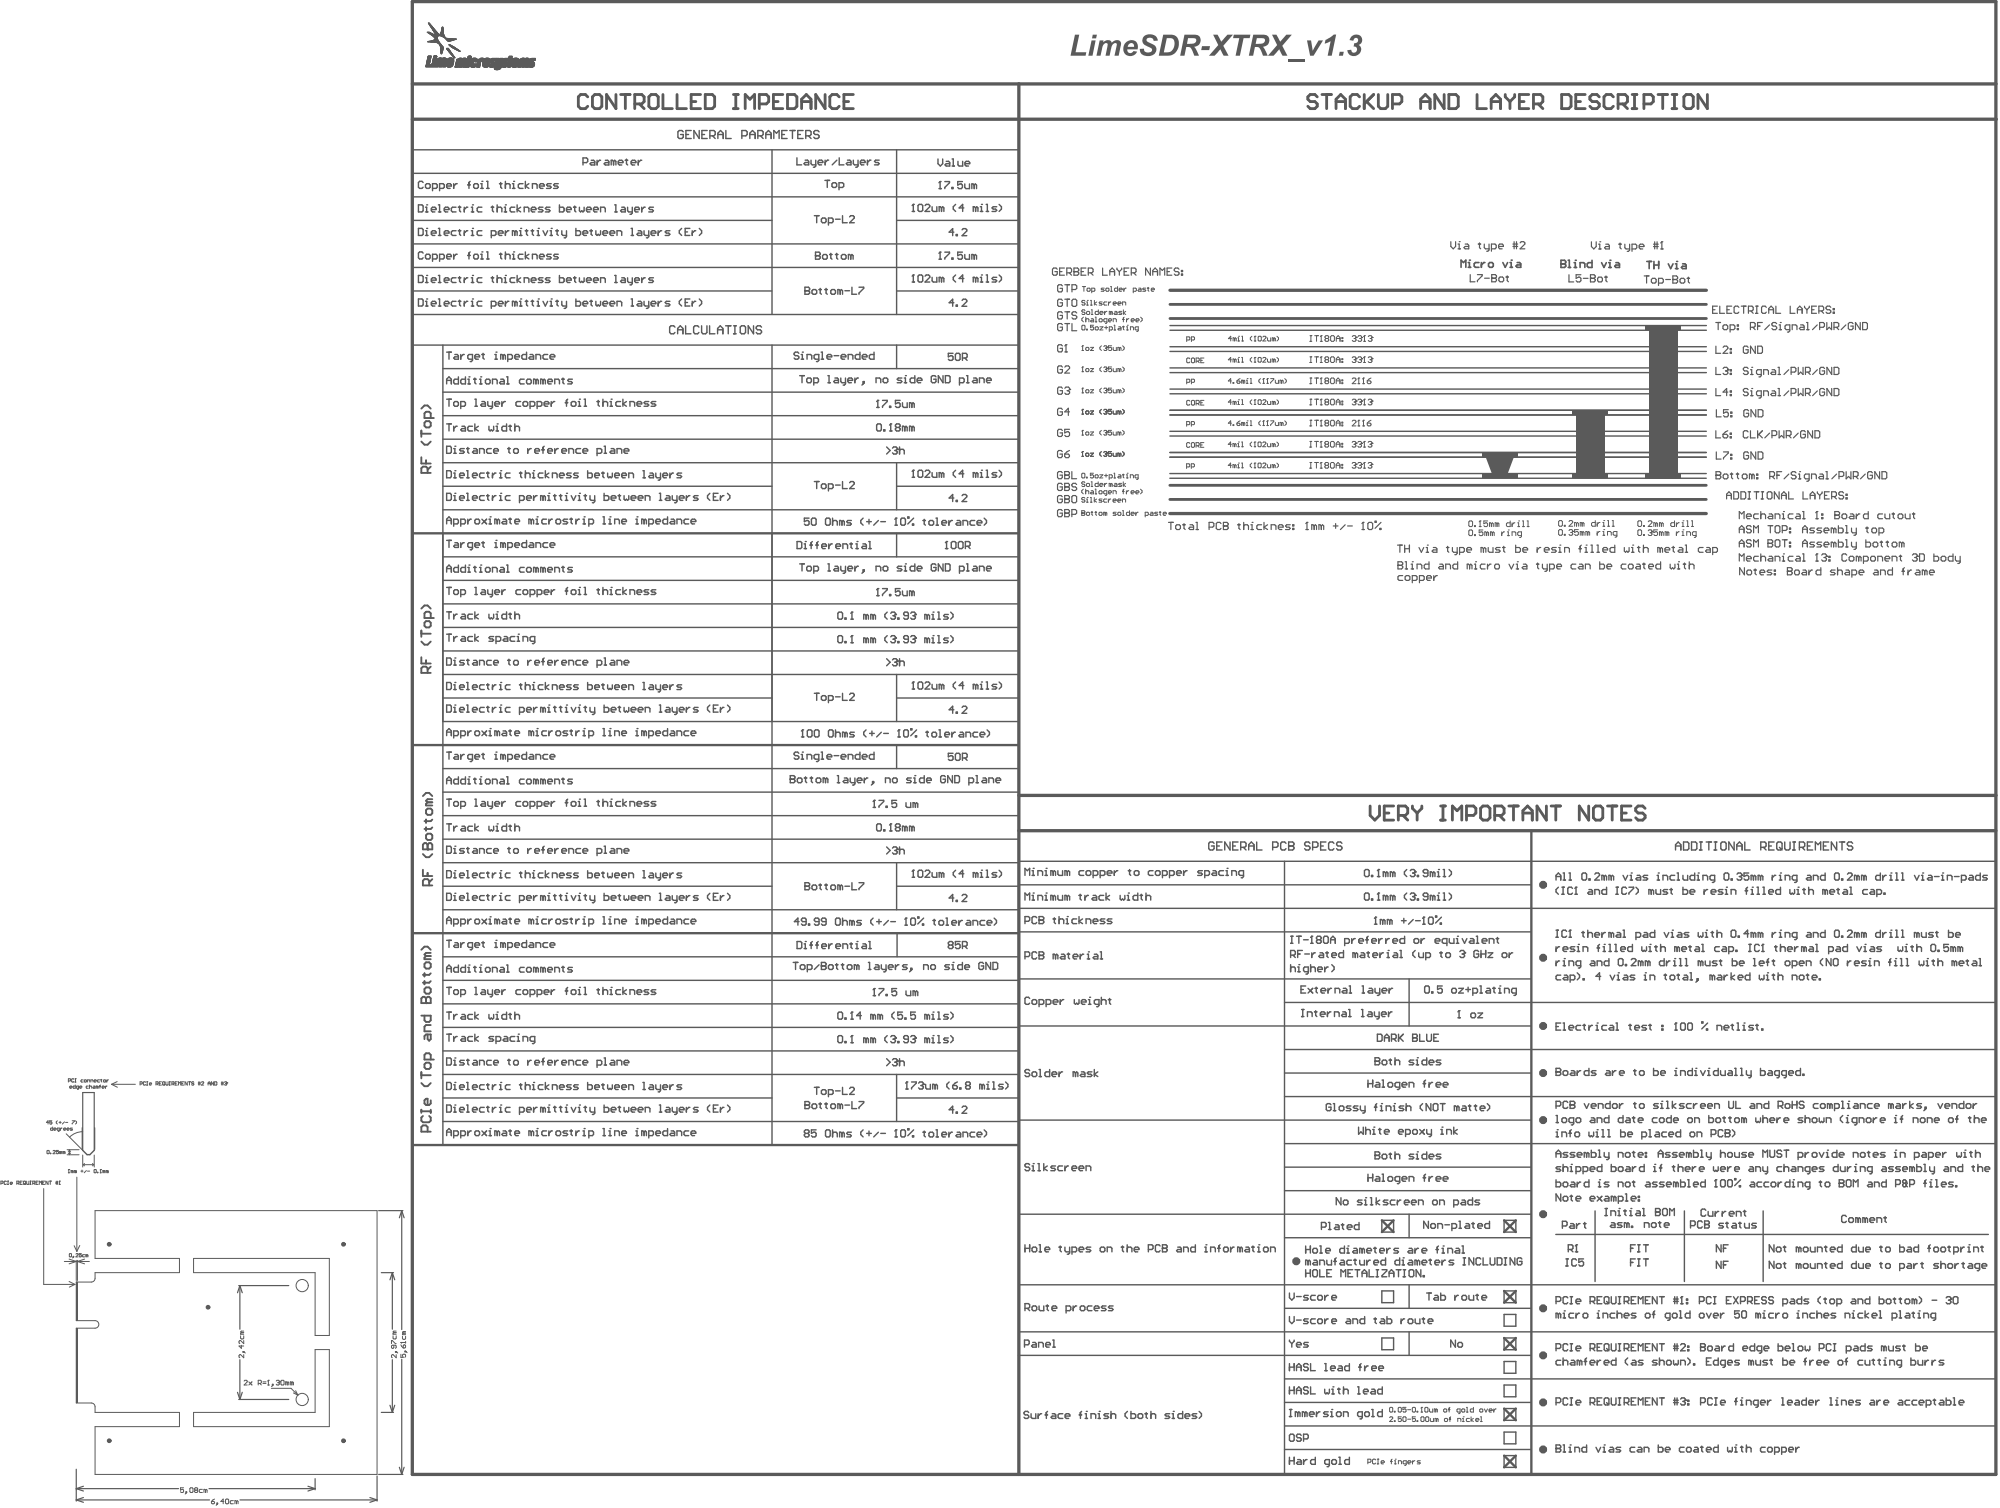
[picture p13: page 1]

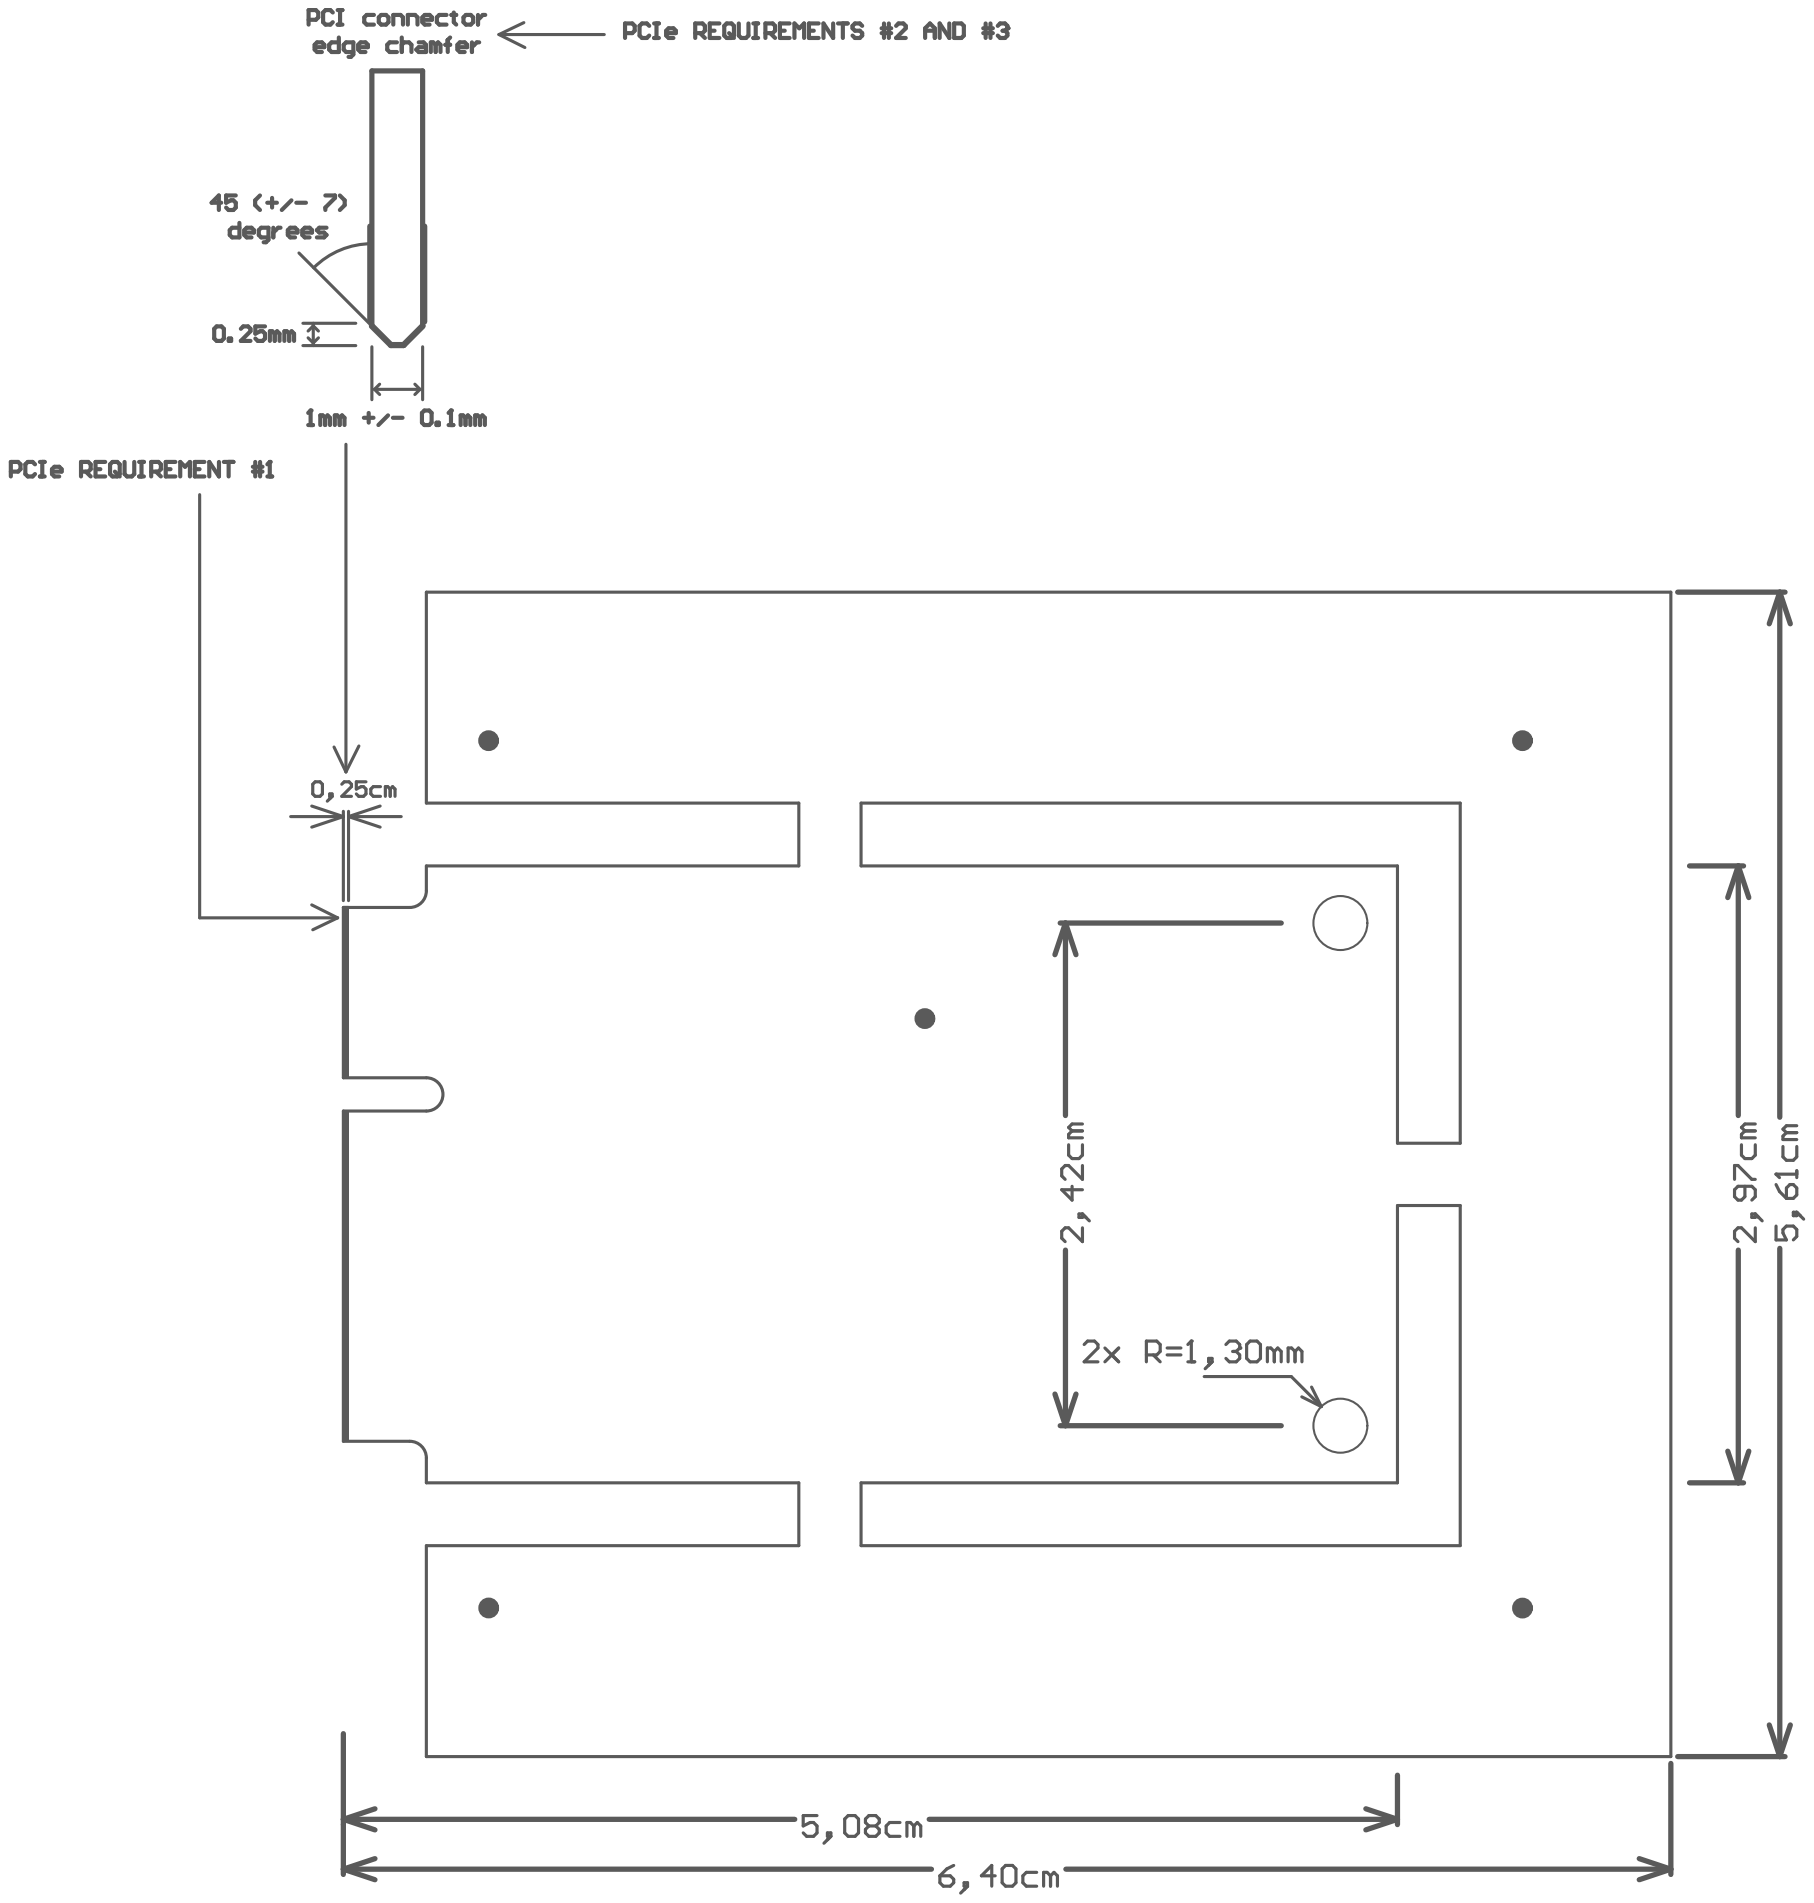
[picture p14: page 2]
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

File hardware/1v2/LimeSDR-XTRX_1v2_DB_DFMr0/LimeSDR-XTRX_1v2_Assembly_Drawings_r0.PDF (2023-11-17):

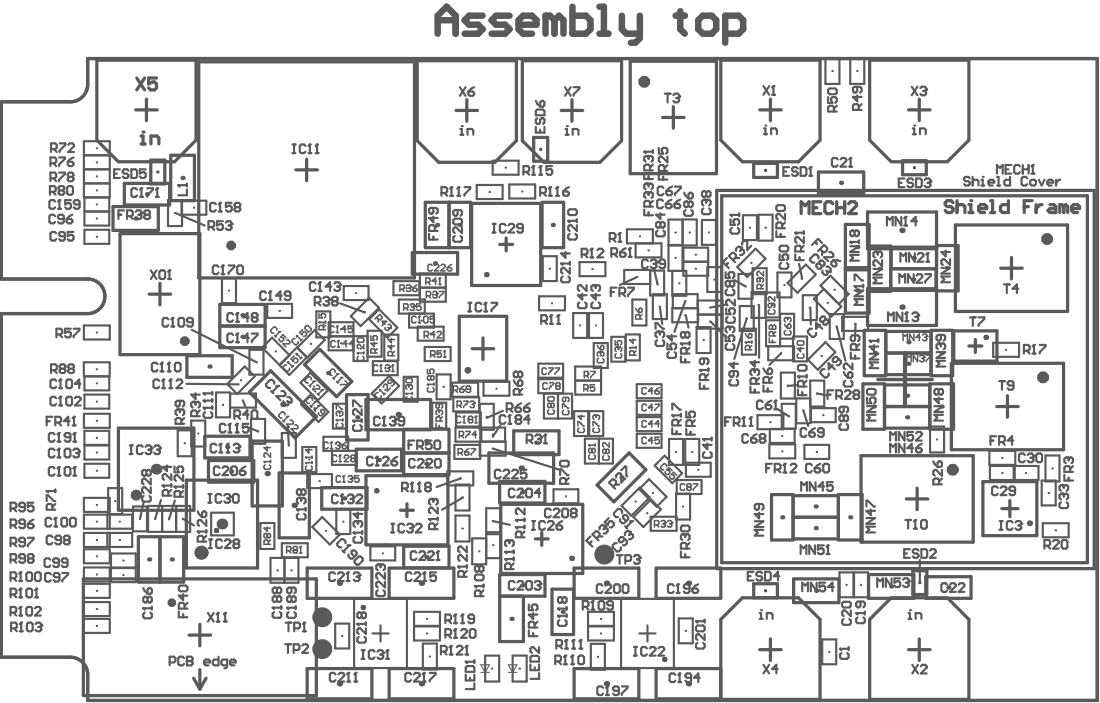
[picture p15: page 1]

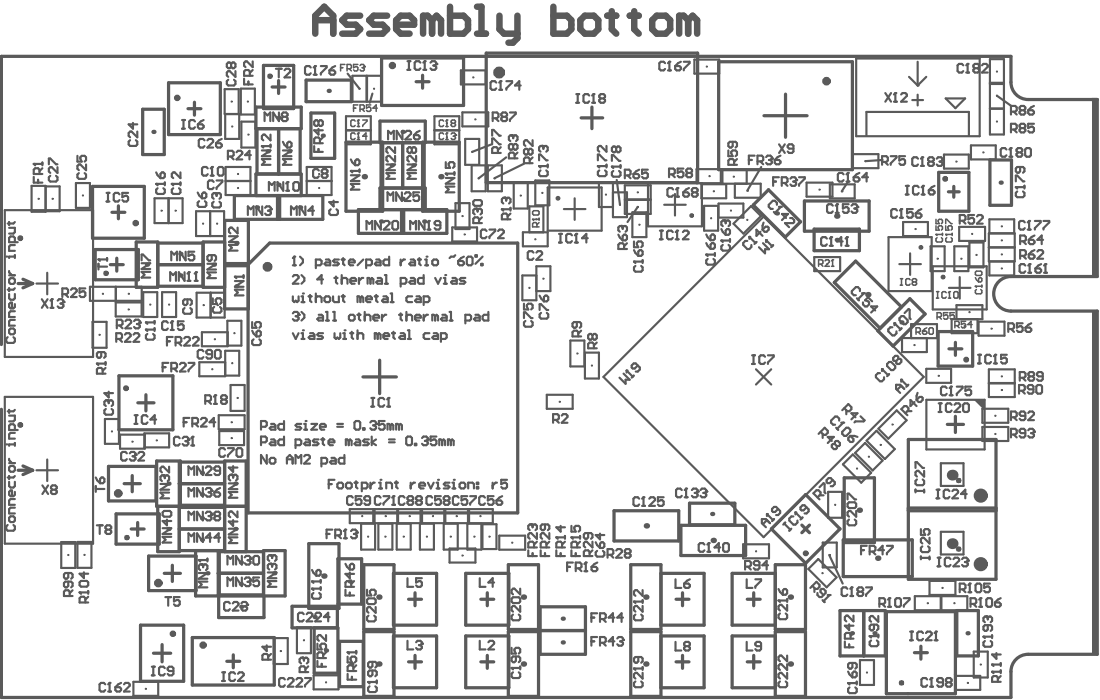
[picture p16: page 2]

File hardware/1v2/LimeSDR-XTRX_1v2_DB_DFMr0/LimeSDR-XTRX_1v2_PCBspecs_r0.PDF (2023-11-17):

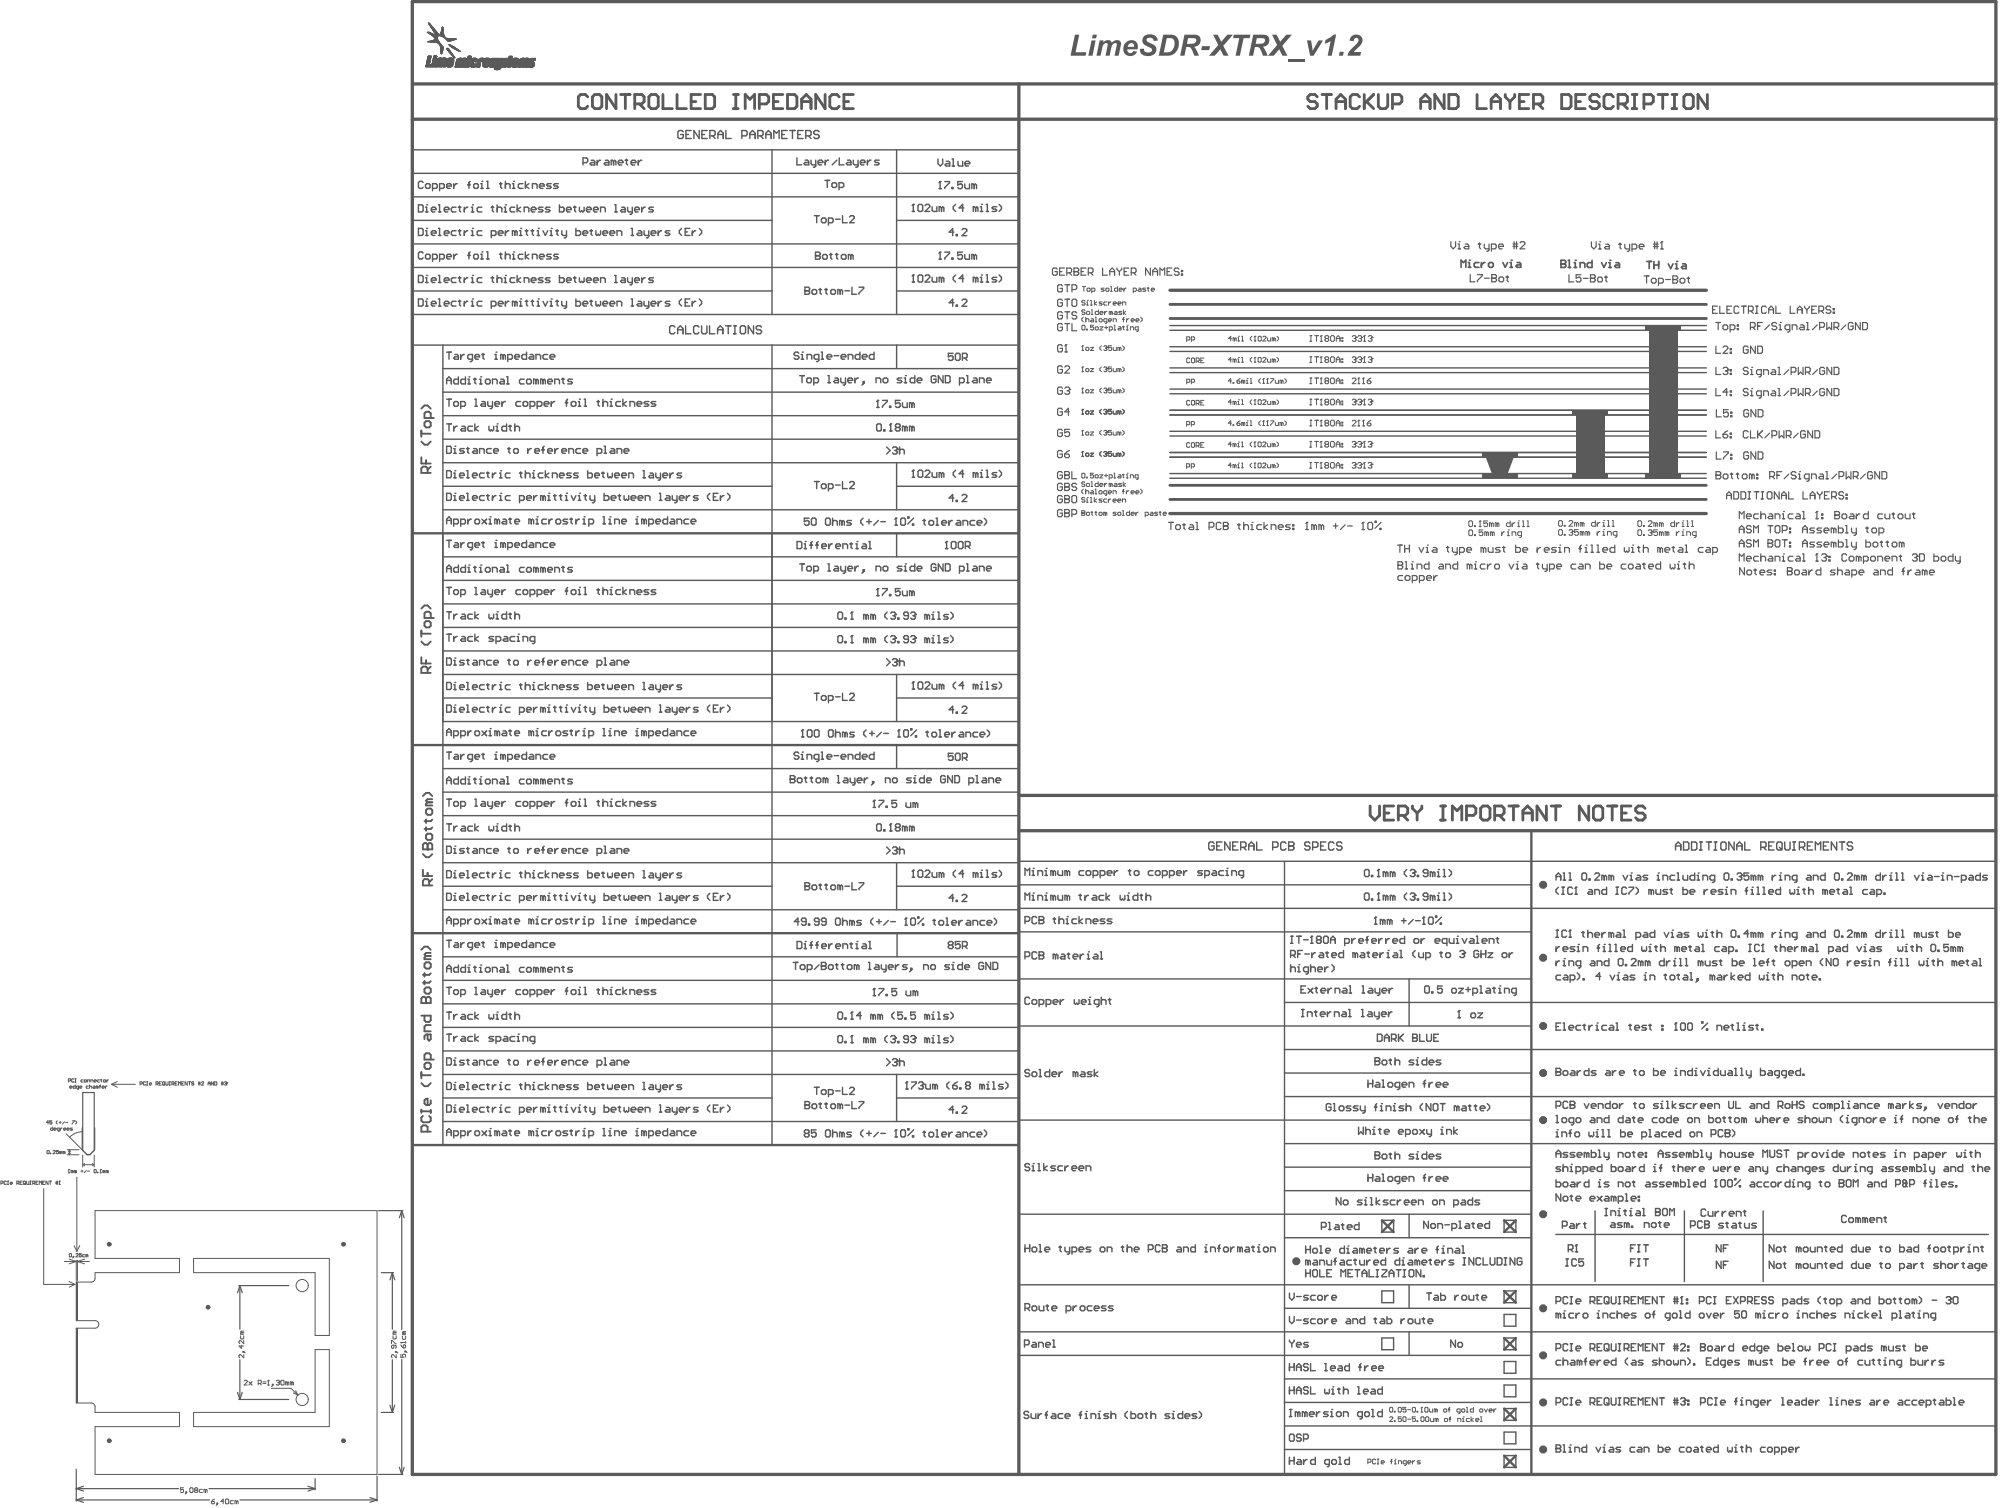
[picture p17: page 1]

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

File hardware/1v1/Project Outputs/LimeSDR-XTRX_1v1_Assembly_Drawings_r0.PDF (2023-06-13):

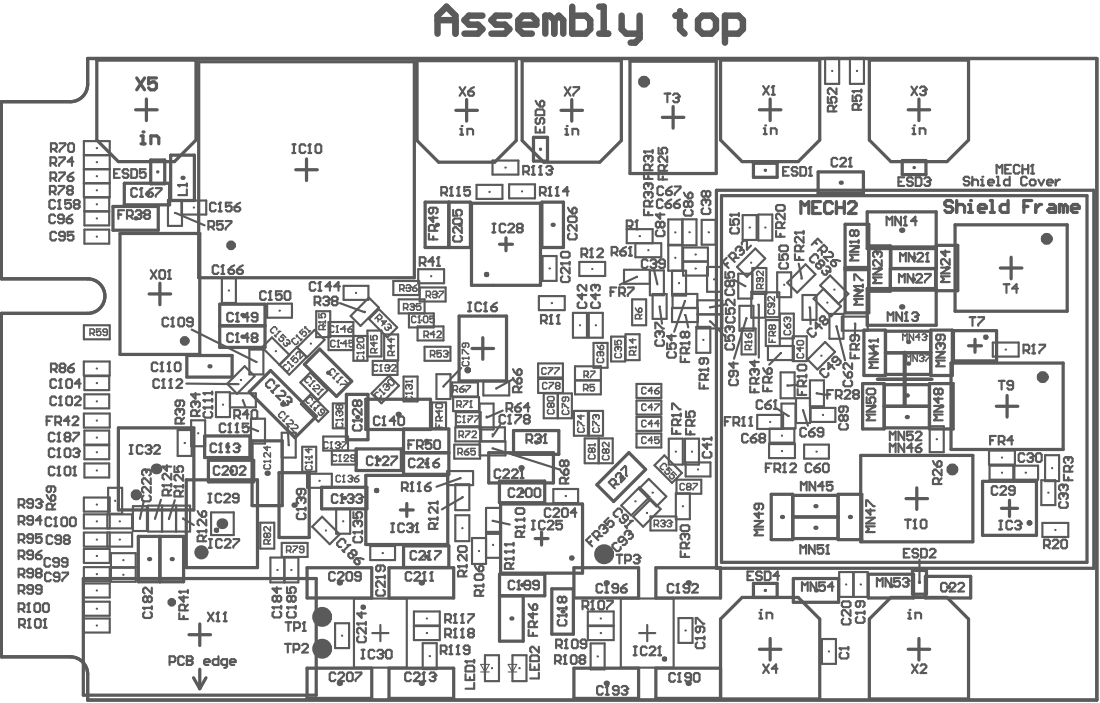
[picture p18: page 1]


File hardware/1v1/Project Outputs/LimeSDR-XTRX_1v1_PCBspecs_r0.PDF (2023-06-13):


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



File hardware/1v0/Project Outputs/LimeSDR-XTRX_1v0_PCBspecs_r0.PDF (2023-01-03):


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

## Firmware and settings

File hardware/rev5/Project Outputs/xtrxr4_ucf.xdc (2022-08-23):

##-----------------------------------------------------------------------------
##
## (c) Copyright 2016 Fairwaves, Inc. All rights reserved.
##
## This file contains confidential and proprietary information
## of Fairwaves, Inc. and is protected under U.S. and
## international copyright and other intellectual property
## laws.
##
## CRITICAL APPLICATIONS
## Fairwaves products are not designed or intended to be fail-
## safe, or for use in any application requiring fail-safe
## performance, such as life-support or safety devices or
## systems, Class III medical devices, nuclear facilities,
## applications related to the deployment of airbags, or any
## other applications that could lead to death, personal
## injury, or severe property or environmental damage
## (individually and collectively, "Critical
## Applications"). Customer assumes the sole risk and
## liability of any use of Fairwaves products in Critical
## Applications, subject only to applicable laws and
## regulations governing limitations on product liability.
##
## THIS COPYRIGHT NOTICE AND DISCLAIMER MUST BE RETAINED AS
## PART OF THIS FILE AT ALL TIMES.
##
##-----------------------------------------------------------------------------
## Project    : XTRXr2 SDR transceiver board based on Artix-7 with 1x/2x PCI Express
## File       : XTRXr2_ucf.xdc
## Version    : 1.0
#
################################################################################################
# User Configuration
# Link Width   - x2
# Link Speed   - gen2
# Family       - artix7
# Part         - xc7a35t
# Package      - cpg236
# Speed grade  - -2
# PCIe Block   - X0Y0
################################################################################################
#
################################################################################################
# User Time Names / User Time Groups / Time Specs
################################################################################################

################################################################################################
# User Physical Constraints
################################################################################################

set_property BITSTREAM.CONFIG.UNUSEDPIN Pulldown [current_design]
set_property BITSTREAM.CONFIG.SPI_BUSWIDTH 4 [current_design]
set_property BITSTREAM.CONFIG.EXTMASTERCCLK_EN Disable [current_design]
set_property BITSTREAM.CONFIG.CONFIGRATE 66 [current_design]
set_property BITSTREAM.GENERAL.COMPRESS TRUE [current_design]
set_property BITSTREAM.CONFIG.SPI_FALL_EDGE YES [current_design]
set_property BITSTREAM.config.SPI_opcode 0x6B [current_design ]
set_property CFGBVS VCCO [current_design]
set_property CONFIG_VOLTAGE 3.3 [current_design]

################################################################################################
# Physical Constraints
################################################################################################
#
# SYS clock 100 MHz (input) signal. The sys_clk_p and sys_clk_n
# signals are the PCI Express reference clock. Virtex-7 GT
# Transceiver architecture requires the use of a dedicated clock
# resources (FPGA input pins) associated with each GT Transceiver.
# To use these pins an IBUFDS primitive (refclk_ibuf) is
# instantiated in user's design.
# Please refer to the Virtex-7 GT Transceiver User Guide
# (UG) for guidelines regarding clock resource selection.
#

#set_property LOC IBUFDS_GTE2_X0Y2 [get_cells refclk_ibuf]
#set_property LOC IBUFDS_GTE2_X0Y2 [get_cells refclk_ibuf]
set_false_path -from [get_ports sys_rst_n]

################################################################################################
# Timing Constraints
################################################################################################
#

create_clock -name usb_phy_clk -period 16 [get_ports usb_clk]


create_clock -name cfg_mclk -period 12  [get_nets cfg_mclk]
create_clock -name sys_clk -period 10   [get_ports sys_clk_p]

create_clock -name clk_vctcxo -period 20 [get_ports fpga_clk_vctcxo]


set_clock_groups -asynchronous -group [get_clocks -include_generated_clocks usb_phy_clk]
set_clock_groups -asynchronous -group [get_clocks -include_generated_clocks sys_clk]
set_clock_groups -asynchronous -group [get_clocks -include_generated_clocks clk_vctcxo]

set_property LOC MMCME2_ADV_X1Y1 [get_cells xlnx_pci_clocking/mmcm_i]

set_false_path -to [get_pins {xlnx_pci_clocking/pclk_i1_bufgctrl.pclk_i1/S0}]
set_false_path -to [get_pins {xlnx_pci_clocking/pclk_i1_bufgctrl.pclk_i1/S1}]
#
#
create_generated_clock -name clk_125mhz_x0y0 [get_pins xlnx_pci_clocking/mmcm_i/CLKOUT0]
create_generated_clock -name clk_250mhz_x0y0 [get_pins xlnx_pci_clocking/mmcm_i/CLKOUT1]
create_generated_clock -name clk_31mhz_x0y0 [get_pins xlnx_pci_clocking/mmcm_i/CLKOUT4]
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

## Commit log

2023-01-02 Move last Fairwaves version of XTRX to archive sub-directory
    [Bill of Materials-XTRXr5(Var 3_3V_I).xls, FPGA.SchDoc, Func Diagram.SchDoc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]
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2023-06-05 Rename PCB project outputs dir. Add licence and README.
    [LimeSDR-XTRX_1v0.GBL, LimeSDR-XTRX_1v0.GBO, LimeSDR-XTRX_1v0.GBP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]
2023-06-13 Added 1v1 version altium files
    [01_Block_Diagram.SchDoc, 02_Power_Diagram.SchDoc, 03_Clock_Diagram.SchDoc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]
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2023-09-04 Added voltage reference pins info
    [10_Power.SchDoc]
2023-09-04 Reverted FPGA configuration flash (IC17) from SO08 to 8-WSON package due mechanical issues (package height)
    [09_Misc.SchDoc]
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2023-11-07 Initial LimeSDR-XTRX v1.2 commit
    [01_Block_Diagram.SchDoc, 02_Power_Diagram.SchDoc, 03_Clock_Diagram.SchDoc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]
2023-11-07 New power rail for VCC1P8_CLK
    [10_Power.SchDoc]
2023-11-07 Removed CLK buffer and connected two level translators
    [09_Misc.SchDoc]
2023-11-07 Connected CLK_OUT and CLK_XO
    [09_Misc.SchDoc]
2023-11-07 Changed level translators power
    [09_Misc.SchDoc]
2023-11-07 Connected LMS_TX_CLK directrly to MUX A line and replaced FPGA_CLK buff with level converter
    [09_Misc.SchDoc]
2023-11-07 Removed MUX A line CLK bias and changed FPGA_CLK level trasnlator input voltage
    [09_Misc.SchDoc]
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2023-11-07 Added CLK_IN level converter
    [09_Misc.SchDoc]
2023-11-08 R1 fit for xoscin_rx
    [05_LMS7002M_Misc.SchDoc]
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2023-11-08 CLK_EXT renamed to CLK_IN_BUFF
    [09_Misc.SchDoc]
2023-11-08 Connected VCCIO_CLK_BIAS to CLK_IN path
    [09_Misc.SchDoc]
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2023-11-08 Added VCCIO_CLK poweer rail selection
    [10_Power.SchDoc]
2023-11-08 Added cap for VCC1P8_CLK
    [09_Misc.SchDoc]
2023-11-08 Added CLP_PATH net class
    [09_Misc.SchDoc]
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2023-11-08 Reannotated, pushed to PCB
    [09_Misc.SchDoc, 10_Power.SchDoc]
2023-11-09 Changed FR53, FR54 package from 0402 to 0201
    [10_Power.SchDoc]
2023-11-09 Changed C164 to 0R
    [09_Misc.SchDoc]
2023-11-09 Changed version to v1.2
    [01_Block_Diagram.SchDoc, 02_Power_Diagram.SchDoc, 03_Clock_Diagram.SchDoc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]
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2023-11-10 Reannotated, PCB passes DRC
    [01_Block_Diagram.SchDoc, 02_Power_Diagram.SchDoc, 03_Clock_Diagram.SchDoc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]
2023-11-10 Changed IC8 VCCB power railt to VCC1P8_CLK
    [09_Misc.SchDoc]
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2023-11-13 Changed HW_VER value from 1 to 2
    [08_FPGA.SchDoc]
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2023-11-14 Changed line color to grey and style to dashed
    [06_LMS7002M_RF.SchDoc]
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2023-11-17 Fixed +2.05V net class
    [10_Power.SchDoc]
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2024-07-26 PCIE_PERST# divider fix: R89 changed to 0R R90 NF
    [09_Misc.SchDoc]
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2024-08-16 Update board-description.rst
    Fixed PPS output typo in Table 14.
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2024-11-22 Changed BOM_VER from 1 to 0 (R49 fit), changed HW_VER from 2 to 3
    [08_FPGA.SchDoc]
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2024-11-22 Renamed switching regulators outputs nets VCC3P3 and VCC_CLK to VCC3P3_SW and VCC_CLK_SW accordingly.
    [10_Power.SchDoc]
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2024-11-22 Added power rails selection for VCC3P3 and VCC_CLK (directly connection option to VCC_EXT).
    [10_Power.SchDoc]
2024-11-26 Replaced single LMS_CLK by two separate LMS_TxPLL_CLK and LMS_RxPLL_CLK clocks
    [05_LMS7002M_Misc.SchDoc]
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2024-11-26 Changed XO DAC from AD5693RACPZ-1RL7 (A grade, INL +-8LSB, internal reference, VLOGIC) to AD5693BCPZ-RL7 (B grade, INL +-3LSB, no internal reference, LDAC).
    [09_Misc.SchDoc]
2024-11-26 Changed R69 to NF, R68 to fit to tie LDAC pin low and DAC updates when new data is written to the input register.
    [09_Misc.SchDoc]
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2024-11-27 Moved XO DAC from sheet 9 to sheet 10
    [09_Misc.SchDoc, 10_Clock.SchDoc]
2024-11-27 The diagram is marked as not conforming to the schematic
    [03_Clock_Diagram.SchDoc]
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2024-11-27 Added parameter PROJECT_VERSION to Revision field, Added parameter SHEET_TOTAL to SheetTotal
    [01_Block_Diagram.SchDoc, 02_Power_Diagram.SchDoc, 03_Clock_Diagram.SchDoc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]
2024-11-27 Removed VCCIO_CLK power rail and voltage selection components
    [11_Power.SchDoc]
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2024-11-27 Moved Mechanical components from sheet 5 to sheet 9
    [05_LMS7002M_Misc.SchDoc, 09_Misc.SchDoc]
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2024-12-02 Fixed XO RF OUT connection
    [10_Clock.SchDoc]
2024-12-02 Added variant default and changed sheet 06 fit status
    [LimeSDR-XTRX_1v3.PrjPcb]
2024-12-02 Updated Fit part status on variant Default in sheet 9
    [LimeSDR-XTRX_1v3.PrjPcb]
2024-12-02 Updated Fit part status on variant Default in sheet 10
    [LimeSDR-XTRX_1v3.PrjPcb]
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2024-12-02 LMK00105 footprint changed on page 10
    Footprint without thermal pad holes used
    [10_Clock.SchDoc]
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2024-12-06 Swapped "Power Distribution" and "Mini PCIe edge connector" chapters
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2025-03-18 Changed IC17 comment from AD5693RACPZ (incorrect) to =Manufacturer Part Number 1 (AD5693BCPZ-RL7)
    [10_Clock.SchDoc]
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2025-04-30 Fixed VCC1P8 net class
    [11_Power.SchDoc]
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2025-09-08 Fixed board size info
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2026-04-30 Changed HW_VER from 3 [0 1 1] to 4 [1 0 0]
    [08_FPGA.SchDoc]
2026-04-30 Replaced LMK00105 clock buffer with LMK00101. Removed 74LVC1G3157FZ4 analog mux for CLK_XO/CLK_IN clock mux.
    No external mux is required because LMK00101 has two inputs.
    [10_Clock.SchDoc, LimeSDR-XTRX_1v4.PrjPcb]
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2026-05-04 Dedicated MHF4 clk in and out connectors
    Connected dedicated CLKOUT MHF4 connector to LMK_CLKOUT1.
    Changed CLK_EXT (In by default, out optional) X7 connector from U.FL to smaller MHF4 connector and changed to CLK_IN_EXT function only (no clkout).
    [10_Clock.SchDoc]
2026-05-04 Changed 1PPS_IN (X6) connector from U.FL to smaller MHF4 connector
    [09_Misc.SchDoc]
2026-05-05 Swapped LMK_CLKOUT1 with LMK_CLKOUT4 for better layout
    [09_Misc.SchDoc, 10_Clock.SchDoc]
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2026-05-07 Changed GNSS power rail from VCC3P3_CLK to VCC3P3 to minimize GNSS module spurs in RF TX.
    [09_Misc.SchDoc]
2026-05-07 Connected LMS_TSTAO, LMS_TSTDO0, LMS_TSTDO1 via 0R NF to X6 (1PPS_IN) for test signals measurement as option.
    [05_LMS7002M_Misc.SchDoc, 09_Misc.SchDoc, LimeSDR-XTRX_1v4.PrjPcb]
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2026-05-07 Changed VDD_TBB (P4) power from VCC1P25_LMS to VCC1P4_LMS.
    [07_LMS7002M_Power.SchDoc, LimeSDR-XTRX_1v4.PrjPcb]
2026-05-07 Replaced USB3333E-GL with USB3317C-GJ-TR due to End of life.
    [09_Misc.SchDoc, LimeSDR-XTRX_1v4.PrjPcb]
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2026-05-11 Fixed all 0201 100nF 1276-1321-1-ND capacitors wrong voltage value (comment) from 6.3V to 10V.
    [06_LMS7002M_RF.SchDoc, 08_FPGA.SchDoc, 09_Misc.SchDoc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]
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2026-05-12 Schematic template updated, output job file names updated
    [01_Block_Diagram.SchDoc, 02_Power_Diagram.SchDoc, 03_Clock_Diagram.SchDoc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]
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2026-05-13 fixed 100, 10V 0201 capacitors part description
    [06_LMS7002M_RF.SchDoc, 08_FPGA.SchDoc, 09_Misc.SchDoc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]
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
